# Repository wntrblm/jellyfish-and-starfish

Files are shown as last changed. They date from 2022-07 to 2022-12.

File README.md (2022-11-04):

# Jellyfish & Starfish

Jellyfish and Starfish are control boards designed for use with the LumenPnP. Starfish controls the base of the machine including X & Y axes and pneumatics. Jellyfish controls the head of the machine including the Z, A, and B axes.

## No support

Jellyfish and Starfish were made for Winterbloom's internal use cases and we don't have the resources to provide support. While we hope that this repository contains useful information for you, please note that issues and pull requests may go unanswered or may be closed without reply.

## License

Jellyfish and Starfish are open source, however, licensing a project like this is a little complicated. Please take a chance to review the [LICENSE](LICENSE.md) file.

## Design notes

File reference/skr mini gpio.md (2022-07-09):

IO00:   TXD0                UART0 TX
IO01:   RXD0                UART0 RX
IO02:   Z-EN                GPIO
IO03:   X-STOP              GPIO
IO04:   Y-STOP              GPIO
IO05:   Y-DIR               GPIO
IO06:   Y-STEP              GPIO
IO07:   Y-EN                GPIO
IO08:   TX4                 UART1 TX    (TMC UART)
IO09:   RX4                 UART1 RX    (TMC UART)
IO10:   X-DIR               GPIO
IO11:   X-STEP              GPIO
IO12:   X-EN                GPIO
IO13:   E0-DIR              GPIO
IO14:   E0-STEP             GPIO
IO15:   E0-EN               GPIO
IO16:   E0-STOP             GPIO
IO17:   FAN1_PWM            PWM0 B
IO18:   FAN2_PWM            PWM1 A
IO19:   Z-STEP              GPIO
IO20:   FAN3_PWM            PWM2 A
IO21:   HB_PWM              PWM2 B
IO22:   P2                  ?
IO23:   HE PWM              PWM3 B
IO24:   RGB                 GPIO
IO25:   Z-STOP              GPIO
IO26:   THB                 ?
IO27:   TH0                 ?
IO28:   Z-DIR               GPIO
IO29:   SERVOS_ADC3         PWM6 B

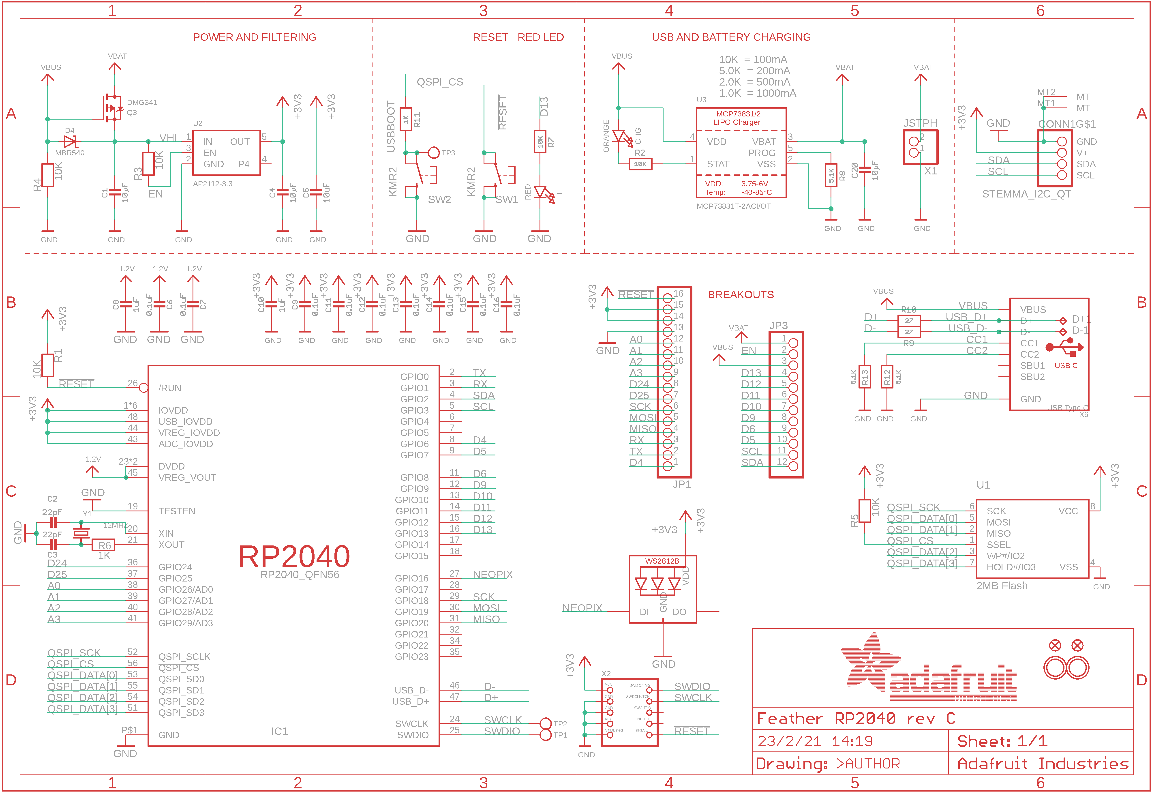
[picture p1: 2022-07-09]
reference/adafruit_products_FeatherRP_sch.png

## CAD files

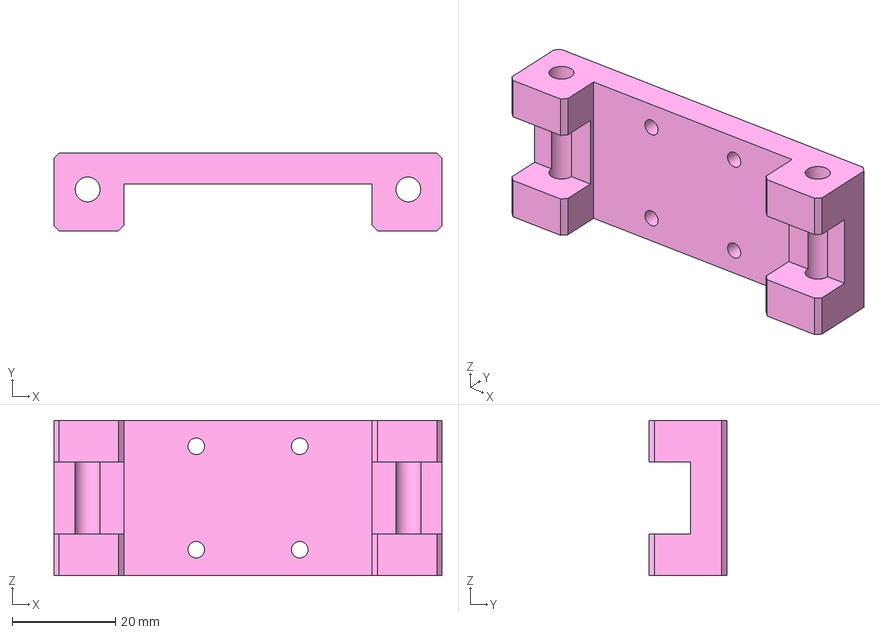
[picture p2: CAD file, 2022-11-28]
mechanical/x-gantry-block-mount-heat-set.FCStd
75.0 x 15.0 x 30.0 mm

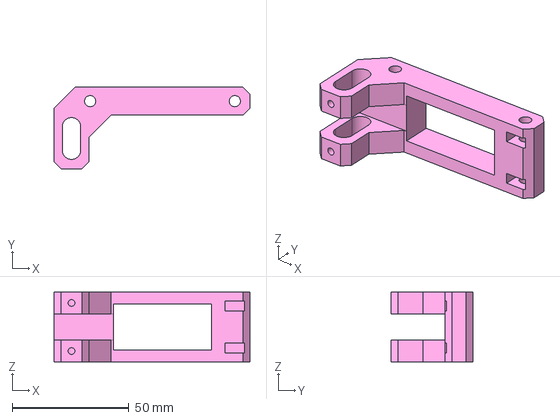
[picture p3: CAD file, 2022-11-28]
mechanical/x-gantry-block-mount-with-prox.FCStd
84.0 x 35.0 x 30.0 mm

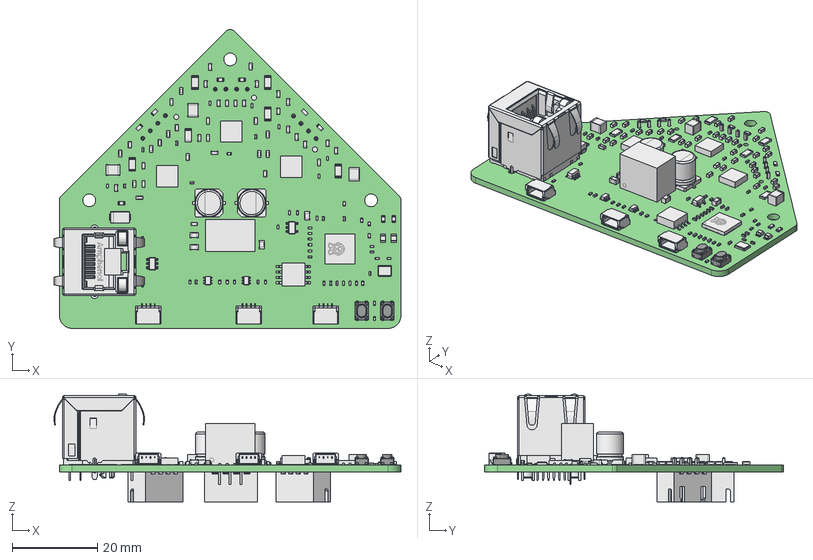
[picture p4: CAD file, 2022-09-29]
mechanical/jellyfish-pcb.FCStd
81.3 x 70.0 x 25.3 mm
jellyfish PCB

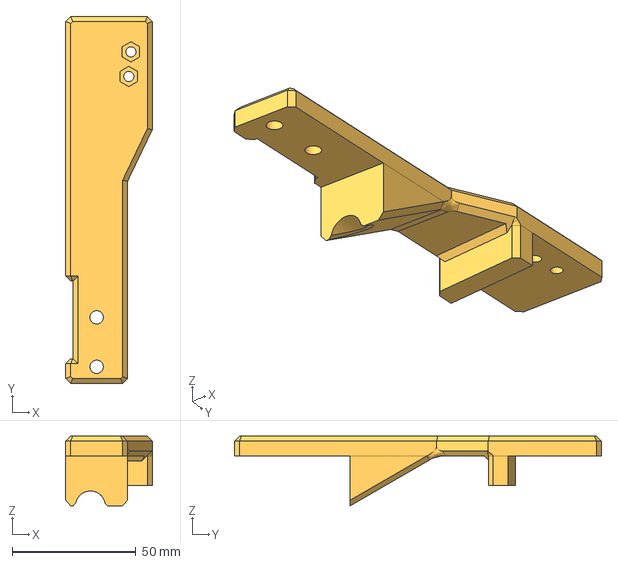
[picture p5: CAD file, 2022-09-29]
mechanical/front-drag-chain-mount.FCStd
35.0 x 148.4 x 28.2 mm

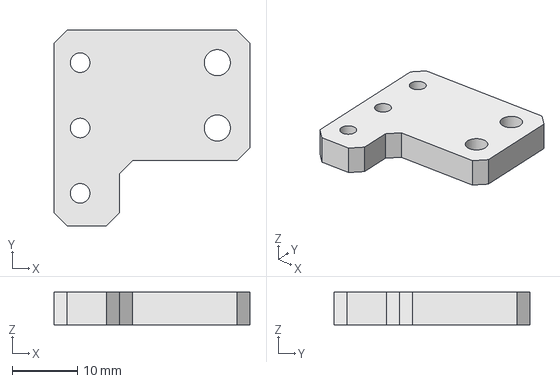
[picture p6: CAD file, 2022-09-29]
mechanical/drag chain mount.FCStd
30.0 x 30.0 x 5.00 mm

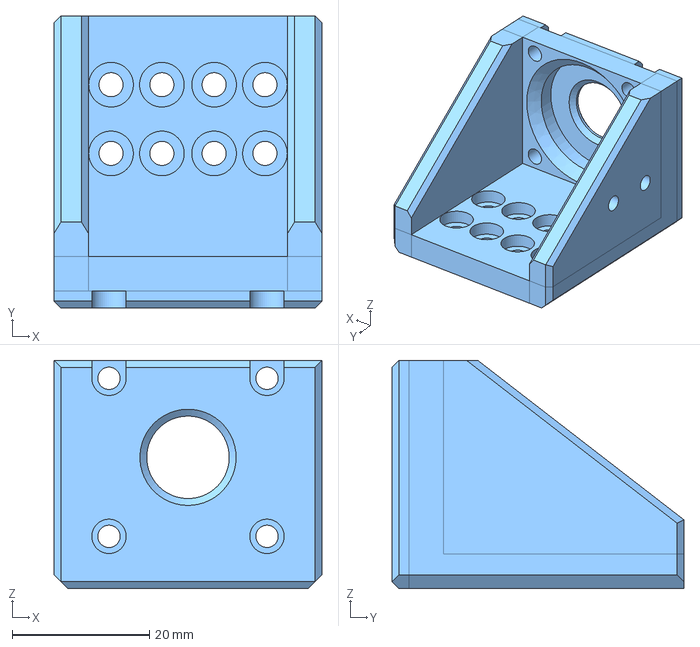
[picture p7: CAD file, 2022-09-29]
mechanical/z-gantry.FCStd
39.0 x 42.5 x 33.2 mm

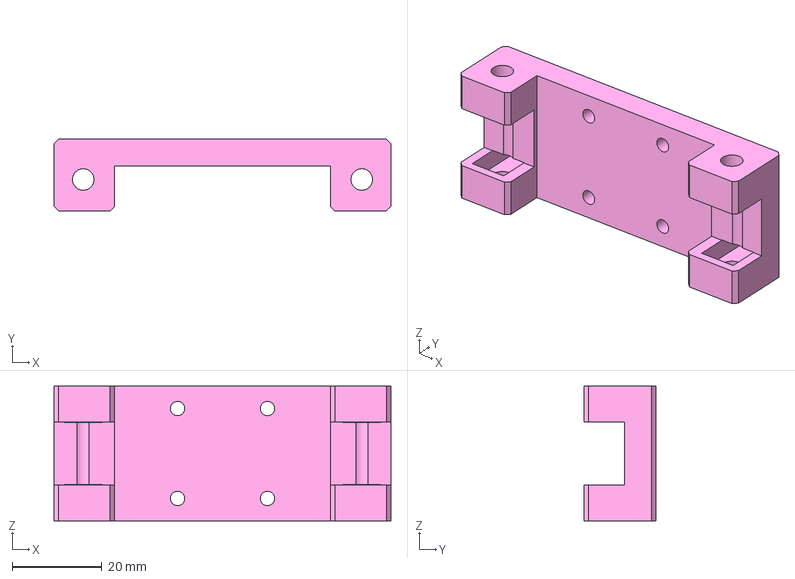
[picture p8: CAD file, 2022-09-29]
mechanical/x-gantry-block-mount.FCStd
75.0 x 16.0 x 30.0 mm

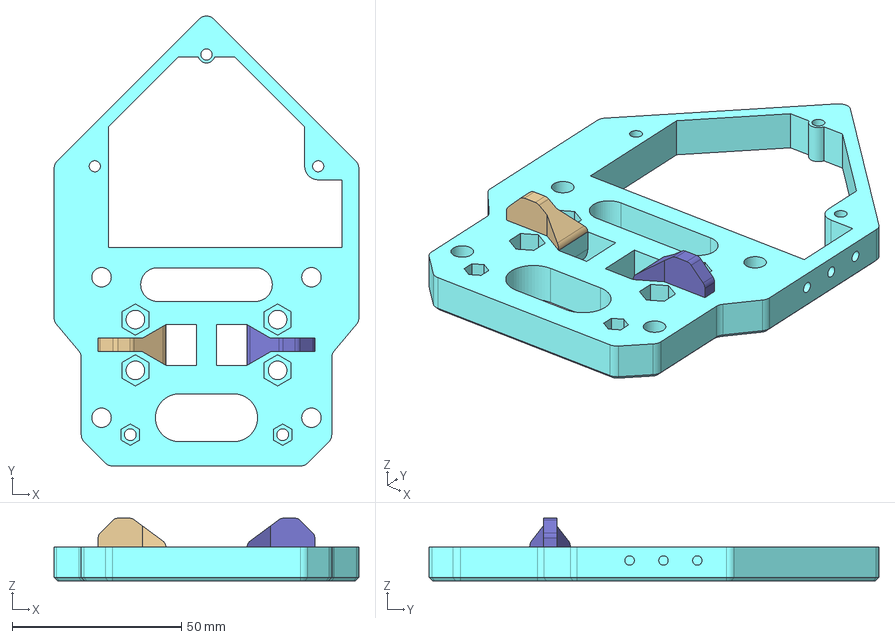
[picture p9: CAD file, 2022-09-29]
mechanical/x-gantry-back.FCStd
90.0 x 132.9 x 18.5 mm
BeltStandoff
BeltStandoff (Mirror #1)

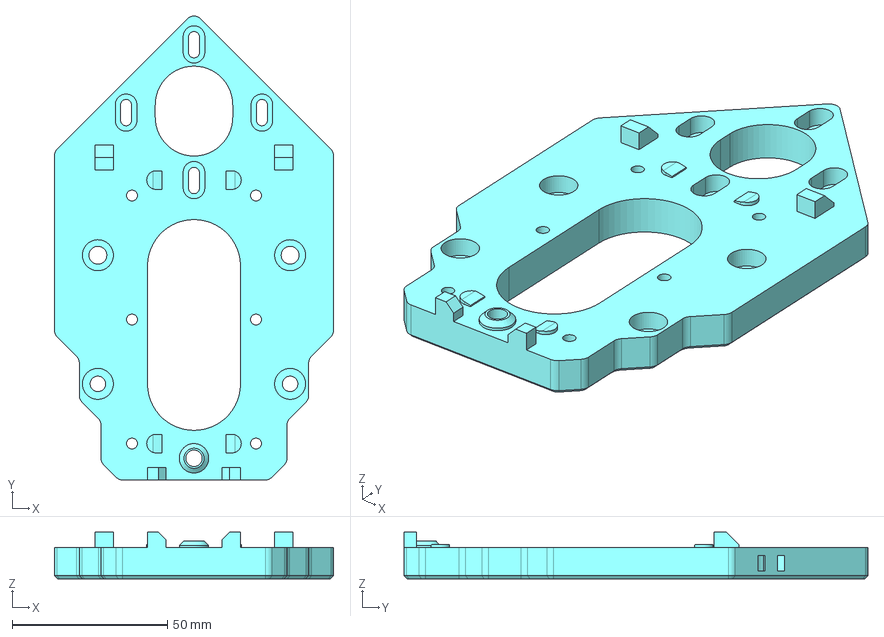
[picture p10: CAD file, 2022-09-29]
mechanical/x-gantry-front.FCStd
90.0 x 149.7 x 15.0 mm

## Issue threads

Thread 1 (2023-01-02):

Some BOM issues i found while sourcing parts

casartar, 2023-01-02:
Starfish BOM issues:
- C203, C1411, C1511, C1611 Capacitor 865080653016 seems to be too big for the footprint | suggestion: same as C5, C22 on Jellyfish EEE-TQV101XAP
- D401 - D404 different mpn, some for 5V instead of 3V3 | suggestion: should all be the same PESD3V3U1UA,115
- F201 fuse should be part of the schematic so it is included in the BOM | no suggestion: forgot to buy one :(
- J407 mpn is missing | suggestion: USB1030-GF-P-B-B
- R202, R1003, R1103, R1303, R1703 footprint is 0402 mpn is for 0603 | suggestion: AC0402FR-075K1L
- R403, R404 mpn missing | suggestion: same as R203
- SW301, SW302 mpn missing | suggestion: TS20-42-25-WT-160-SMT-TR
- U601, U701 pressure range missing

Jellyfish BOM issues:
- C1-C3 mpn missing | suggestion: C2012X7R1V475K125AE
- FB1-FB14 Value says 50 Ohm at 100 MHz but the Datasheet of the mpn says 120 Ohm and there are different ratings some 2A some 3A
- R3, R16 value is 100 mpn is for 10k | suggestion: AC0402JR-07100RL
- R18, R19, R21, R22, R24, R25 value is 220m but mpn is for 240m and it is different to starfish - i tried to understand this from the datasheed but didn't :|
- R1, R2, R15, R26, R27 value is 5k1 mpn is for 10k | suggestion: same as in starfish AC0402FR-075K1L
- R10, R28 mpn is missing | suggestion: RC0603JR-7W1KL

Jellyfish-Tailboard BOM issues:
- C1-C3 mpn missing | suggestion: EMZR500ARA101MF80G
- R1, R2, R3 value typo and footprint is 0402 but mpn is for 0603 | suggestion: AC0402FR-075K1L

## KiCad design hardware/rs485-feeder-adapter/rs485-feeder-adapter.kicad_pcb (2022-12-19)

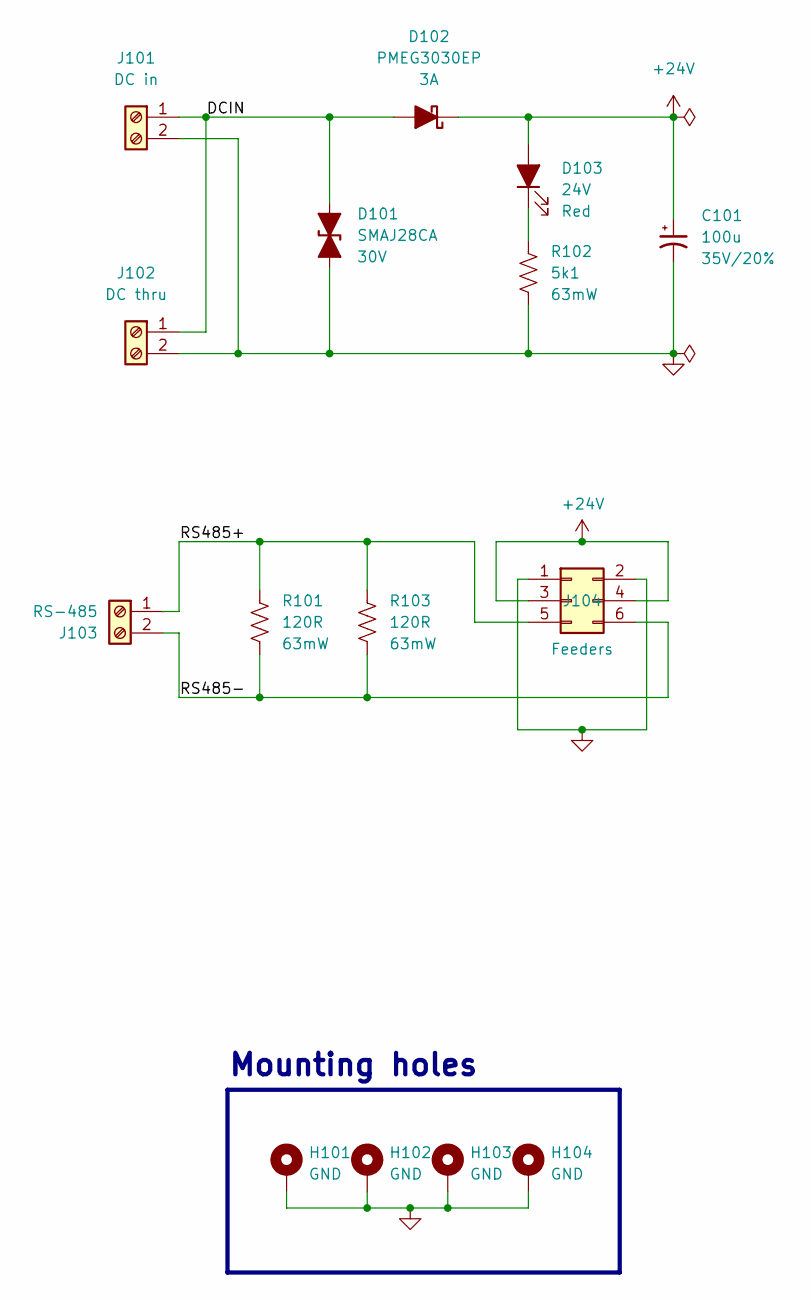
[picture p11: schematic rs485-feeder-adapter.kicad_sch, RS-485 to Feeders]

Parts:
C101: 100u; CP_Elec_6.3x9.9; Rating 35V/20%; mpn 865080653016, UWT1V221MNL1GS
D101: SMAJ28CA; D_SMA; Rating 30V; mpn SMAJ28CA
D102: PMEG3030EP; D_SOD-128; Rating 3A; mpn PMEG3030EP,115
D103: 24V; LED_0805_Kingbright_APT2012; Rating Red; mpn APT2012EC
H101, H102, H103, H104: GND; MountingHole_3mm_Pad
J101: DC in; TerminalBlock_CUI_TB002-500_1x02_P5.00mm_Vertical; mpn TB002-500-02BE
J102: DC thru; TerminalBlock_CUI_TB002-500_1x02_P5.00mm_Vertical; mpn TB002-500-02BE
J103: RS-485; TerminalBlock_4UCON_1x02_P3.50mm_Horizontal
J104: Feeders; IDC-Header_2x03_P2.54mm_Vertical
R101, R103: 120R; R_0402_HandSolder; Rating 63mW; mpn CRGCQ0402F120R
R102: 5k1; R_0402_HandSolder; Rating 63mW; mpn AC0603FR-075K1L

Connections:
+24V: C101.1, D102.1 (K), D103.2 (A), J104.3, J104.4
/DCIN: D101.1 (A1), D102.2 (A), J101.1, J102.1
/RS485+: J103.1, J104.5, R101.1, R103.1
/RS485-: J103.2, J104.6, R101.2, R103.2
GND: C101.2, D101.2 (A2), H101.1, H102.1, H103.1, H104.1, J101.2, J102.2, J104.1, J104.2, R102.2
unnamed: D103.1 (K), R102.1

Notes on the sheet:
Mounting holes

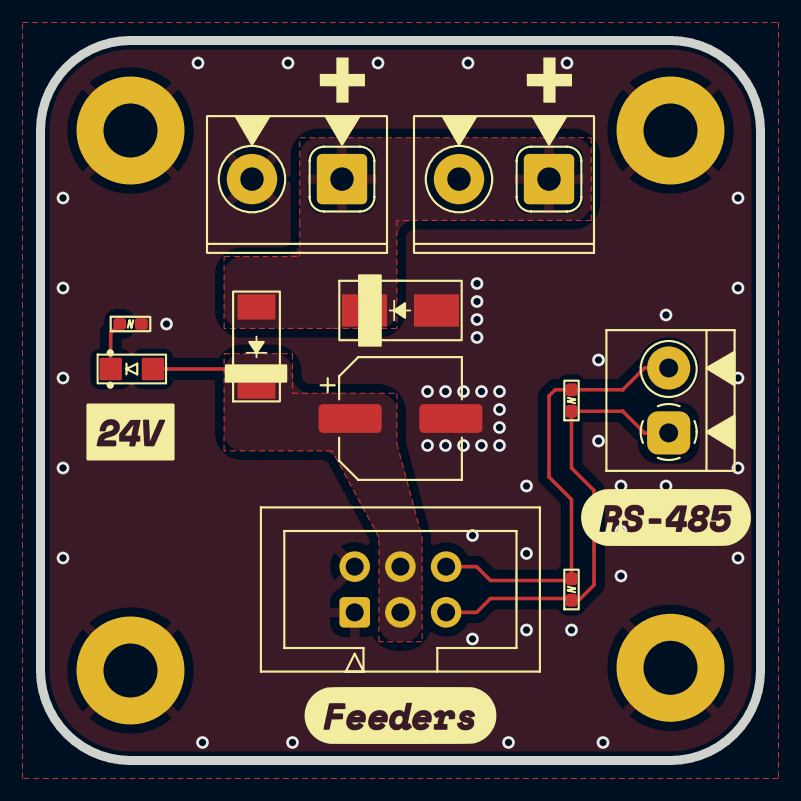
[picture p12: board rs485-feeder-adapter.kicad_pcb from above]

Board: 2 copper layers, 40.0 x 40.0 mm, 15 parts (0 on the bottom side), 6 nets.

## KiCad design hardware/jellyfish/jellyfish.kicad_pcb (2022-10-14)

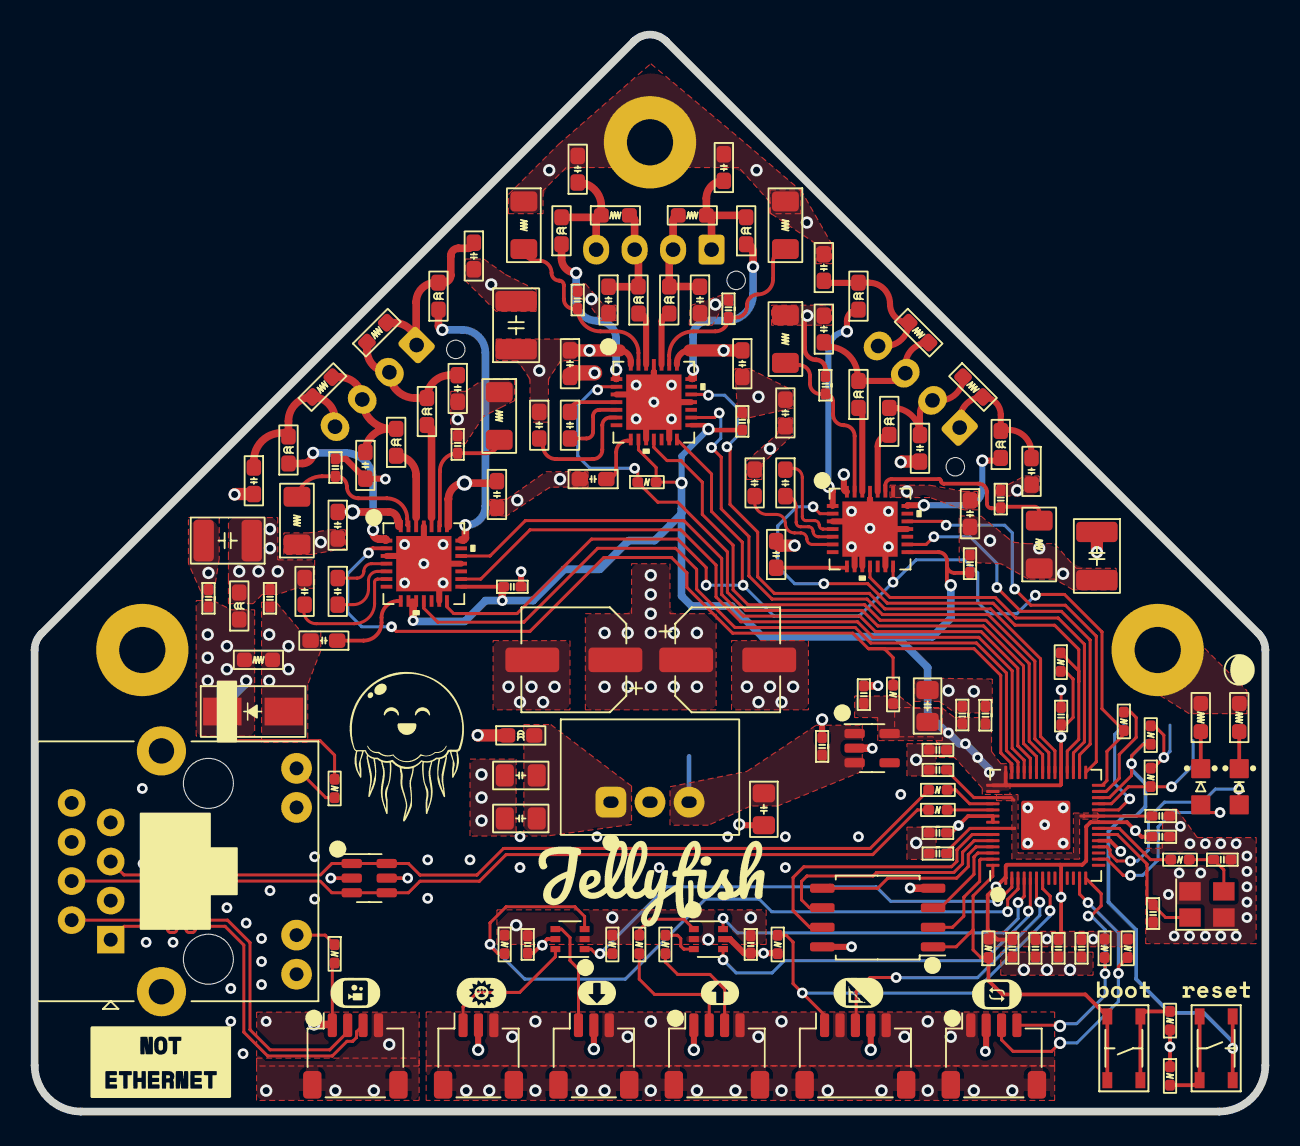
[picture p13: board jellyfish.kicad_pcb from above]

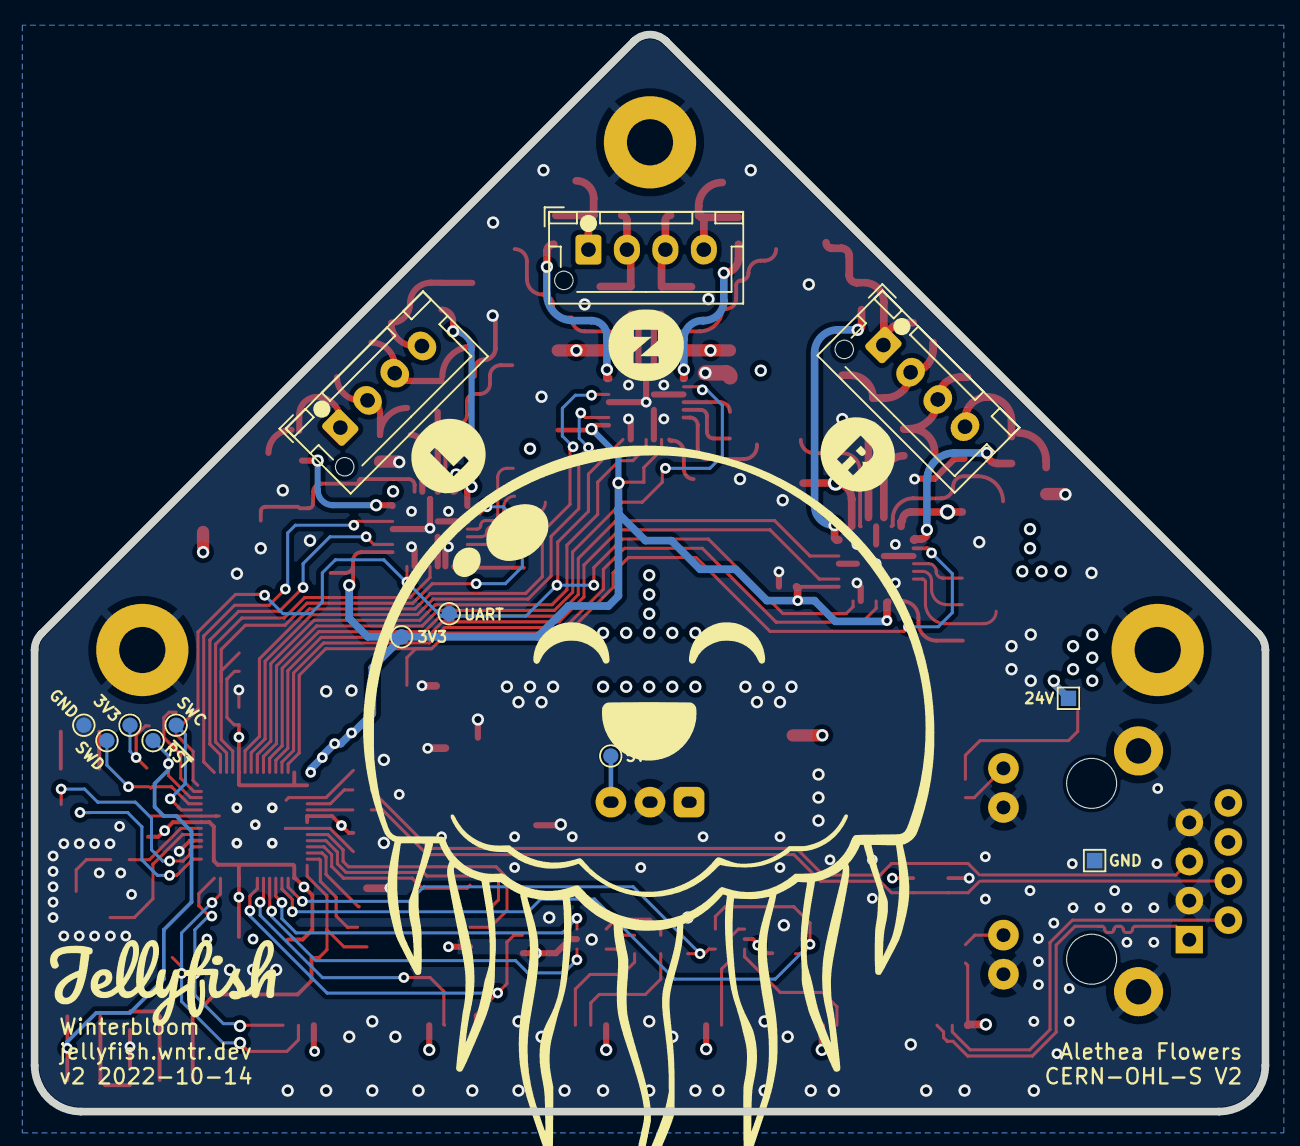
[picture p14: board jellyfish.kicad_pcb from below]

Board: 4 copper layers, 80.0 x 70.0 mm, 155 parts (13 on the bottom side), 103 nets.

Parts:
C1, C8, C9, C11, C12, C13, C14, C15, C16, C17, C20, C21, C25, C27, C29, C32, C33, C43, C46, C47, C57, C60, C61: 100n; C_0402_HandSolder
C2: 4.7u; C_0805_HandSolder
C3, C4: 22u; C_0805_HandSolder
C5, C22: 100u; CP_Elec_6.3x7.7
C6, C7, C18, C19, C26: 1u; C_0402_HandSolder
C10: 10u; C_0805_HandSolder
C23, C24: 15p; C_0402_HandSolder
C28, C42, C56: 22n; C_0603_HandSolder
C30, C36, C37, C44, C50, C51, C58, C64, C65: 100n; C_0603_HandSolder
C31, C45, C59: 4.7u; C_0603_HandSolder
C35, C49, C63: 10u; C_1210_HandSolder
C38, C39, C40, C41, C52, C53, C54, C55, C66, C67, C68, C69: 470p; C_0603_HandSolder
D1: AUX; LED_0805_Kingbright_APT2012
D2: SMAJ28A; D_SMA
D4: ACT; LED_0805_Kingbright_APT2012
FB1, FB2, FB3, FB4, FB5, FB6, FB7, FB8, FB9, FB10, FB11, FB12, FB13, FB14: 50Ω @ 100MHz; L_0603_HandSolder
H1, H2, H3: GND; MountingHole_3mm_Pad
J1: INS; JST_SH_SM04B-SRSS-TB_1x04-1MP_P1.00mm_Horizontal
J2: 8P8C_LED_Shielded; RJ45_Amphenol_RJE45-188-1411_Vertical
J3: CAM; JST_SH_SM04B-SRSS-TB_1x04-1MP_P1.00mm_Horizontal
J4: CAMLED; JST_SH_SM03B-SRSS-TB_1x03-1MP_P1.00mm_Horizontal
J5: OUT1; JST_SH_SM03B-SRSS-TB_1x03-1MP_P1.00mm_Horizontal
J6: BLTOUCH; JST_SH_SM05B-SRSS-TB_1x05-1MP_P1.00mm_Horizontal
J7, J8, J9: MOTOR; JST_XH_B4B-XH-AM_1x04_P2.50mm_Vertical
J10: Stemma QT; JST_SH_SM04B-SRSS-TB_1x04-1MP_P1.00mm_Horizontal
R1, R2, R15, R26, R27: 5.1k; R_0402_HandSolder
R3, R16: 100; R_0402_HandSolder
R4, R5, R12, R13, R14, R17, R20, R23: 10k; R_0402_HandSolder
R6, R7: 27R; R_0402_HandSolder
R8, R9, R11, R29: 1k; R_0402_HandSolder
R10, R28: 1k; R_0603_HandSolder
R18, R19, R21, R22, R24, R25: 220m; R_1206_HandSolder
RV1, RV2, RV3, RV4, RV5, RV6, RV7: 35V; R_0603_HandSolder
SW1: BOOTSEL; Tactile_Switch_4.2mm
SW2: RESET; Tactile_Switch_4.2mm
TP1: GND; TestPoint_Pad_1.0x1.0mm
TP2: 24V; TestPoint_Pad_1.0x1.0mm
TP3: 5V; TestPoint_Pad_D1.0mm
TP4, TP6: 3V3; TestPoint_Pad_D1.0mm
TP5: GND; TestPoint_Pad_D1.0mm
TP7: ~{RST}; TestPoint_Pad_D1.0mm
TP8: SWD; TestPoint_Pad_D1.0mm
TP9: SWC; TestPoint_Pad_D1.0mm
TP17: UART; TestPoint_Pad_D1.0mm
U1: VX7805-500; Converter_DCDC_CUI_VX78-500_THT
U2: MIC5317-3.3; SOT-23-5
U3: RP2040; RP2040-QFN-56
U4: W25Q128JVS; SOIC-8_5.23x5.23mm_P1.27mm
U5, U7: 74HC2G34; SOT-363_SC-70-6
U6: TVS; SOT-23-6
U8, U9, U10: TMC2209; TMC2209-LA
Y1: 12MHz; Crystal_SMD_Abracon_ABM8G-4Pin_3.2x2.5mm

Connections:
+1V1: C19.1, C20.1, C21.1, U3.23 (DVDD), U3.45 (VREG_VOUT), U3.50 (DVDD)
+3V3: C1.1, C7.1, C10.1, C11.1, C12.1, C13.1, C14.1, C15.1, C16.1, C17.1, C18.1, C25.1, C26.1, C29.1, C43.1, C57.1, J10.2, R4.2, R5.1, R12.2, R15.2, R17.2, R20.2, R23.2, R26.2, R27.2, TP4.1, TP6.1, U2.5 (OUT), U3.1 (IOVDD), U3.10 (IOVDD), U3.22 (IOVDD), U3.33 (IOVDD), U3.42 (IOVDD), U3.43 (ADC_AVDD), U3.44 (VREG_IN), U3.48 (USB_VDD), U3.49 (IOVDD), U4.8 (VCC), U5.5 (VCC), U8.15 (VCC_IO), U9.9 (MS1_AD0), U9.15 (VCC_IO), U10.9 (MS1_AD0), U10.10 (MS2_AD1), U10.15 (VCC_IO)
+5V: C4.1, C6.1, C27.1, J1.1, J3.1, J4.2, J5.2, J6.4, R1.2, TP3.1, U1.3 (Vout), U2.1 (IN), U2.3 (EN), U6.5 (VBUS), U7.5 (VCC)
+24V: C5.1, C9.1, C22.1, C30.1, C35.1, C36.1, C37.1, C44.1, C49.1, C50.1, C51.1, C58.1, C63.1, C64.1, C65.1, FB1.2, U8.22 (VS), U8.28 (VS), U9.22 (VS), U9.28 (VS), U10.22 (VS), U10.28 (VS)
/Connections/AUX_OUT: R14.2, U3.3 (GPIO1), U7.3 (2A)
/Connections/BLTOUCH_CONTROL: J6.3, U3.6 (GPIO4)
/Connections/BLTOUCH_OUT: J6.1, R15.1, U3.7 (GPIO5)
/Connections/CAM_D+: J2.1, J3.3
/Connections/CAM_D-: J2.2, J3.2
/Connections/CAM_LED: R13.2, U3.2 (GPIO0), U7.1 (1A)
/Connections/IN_1: U3.4 (GPIO2), U5.6 (1Y)
/Connections/IN_2: U3.5 (GPIO3), U5.4 (2Y)
/Connections/MCU_D+: J2.4, R6.1, U6.3 (D+), U6.4 (D+)
/Connections/MCU_D-: J2.5, R7.1, U6.1 (D-), U6.6 (D-)
/Connections/QWIIC_SCL: J10.4, R27.1, U3.14 (GPIO11)
/Connections/QWIIC_SDA: J10.3, R26.1, U3.13 (GPIO10)
/Left Motor/5VOUT: C31.1, U8.8 (5VOUT)
/Left Motor/BRA: C33.1, R19.2, U8.23 (BRA)
/Left Motor/BRB: C32.1, R18.2, U8.27 (BRB)
/Left Motor/CPI: C28.2, U8.5 (CPI)
/Left Motor/CPO: C28.1, U8.4 (CPO)
/Left Motor/DIAG: U3.31 (GPIO20), U8.11 (DIAG)
/Left Motor/DIR: U3.29 (GPIO18), U8.19 (DIR)
/Left Motor/ENN: R17.1, U3.32 (GPIO21), U8.2 (ENN)
/Left Motor/OA1: FB4.1, U8.24 (OA1)
/Left Motor/OA2: FB5.1, U8.21 (OA2)
/Left Motor/OB1: FB3.1, U8.26 (OB1)
/Left Motor/OB2: FB2.1, U8.1 (OB2)
/Left Motor/STEP: U3.30 (GPIO19), U8.16 (STEP)
/Left Motor/VCP: C30.2, U8.6 (VCP)
/Microcontroller/ACT_LED: D4.2 (A), U3.18 (GPIO15)
/Microcontroller/AUX_LED: D1.2 (A), U3.16 (GPIO13)
/Microcontroller/M1_DIAG: U3.36 (GPIO24), U9.11 (DIAG)
/Microcontroller/M1_DIR: U3.34 (GPIO22), U9.19 (DIR)
/Microcontroller/M1_EN: R20.1, U3.37 (GPIO25), U9.2 (ENN)
/Microcontroller/M1_STEP: U3.35 (GPIO23), U9.16 (STEP)
/Microcontroller/M2_DIAG: U3.40 (GPIO28_ADC2), U10.11 (DIAG)
/Microcontroller/M2_DIR: U3.38 (GPIO26_ADC0), U10.19 (DIR)
/Microcontroller/M2_EN: R23.1, U3.41 (GPIO29_ADC3), U10.2 (ENN)
/Microcontroller/M2_STEP: U3.39 (GPIO27_ADC1), U10.16 (STEP)
/Microcontroller/QSPI_CS: R12.1, SW1.1, U3.56 (QSPI_SS), U4.1 (~CS)
/Microcontroller/QSPI_SCLK: U3.52 (QSPI_SCLK), U4.6 (CLK)
/Microcontroller/QSPI_SD0: U3.53 (QSPI_SD0), U4.5 (DI(IO0))
/Microcontroller/QSPI_SD1: U3.55 (QSPI_SD1), U4.2 (DO(IO1))
/Microcontroller/QSPI_SD2: U3.54 (QSPI_SD2), U4.3 (IO2)
/Microcontroller/QSPI_SD3: U3.51 (QSPI_SD3), U4.7 (IO3)
/Microcontroller/RUN: R4.1, SW2.1, TP7.1, U3.26 (RUN)
/Microcontroller/SWCLK: TP9.1, U3.24 (SWCLK)
/Microcontroller/SWD: R5.2, TP8.1, U3.25 (SWD)
/Microcontroller/UART1_TX: R8.1, U3.27 (GPIO16)
/Microcontroller/USB_D+: R6.2, U3.47 (USB_DP)
/Microcontroller/USB_D-: R7.2, U3.46 (USB_DM)
/Microcontroller/XIN: C23.1, U3.20 (XIN), Y1.1
/Microcontroller/XOUT: R11.1, U3.21 (XOUT)
/Power/VIN_FILTERED: C2.1, C3.1, FB14.2, U1.1 (Vin)
/Right Motor/5VOUT: C59.1, U10.8 (5VOUT)
/Right Motor/BRA: C61.1, R25.2, U10.23 (BRA)
/Right Motor/BRB: C60.1, R24.2, U10.27 (BRB)
/Right Motor/CPI: C56.2, U10.5 (CPI)
/Right Motor/CPO: C56.1, U10.4 (CPO)
/Right Motor/OA1: FB12.1, U10.24 (OA1)
/Right Motor/OA2: FB13.1, U10.21 (OA2)
/Right Motor/OB1: FB11.1, U10.26 (OB1)
/Right Motor/OB2: FB10.1, U10.1 (OB2)
/Right Motor/VCP: C58.2, U10.6 (VCP)
/TMC_UART: R8.2, TP17.1, U3.28 (GPIO17), U8.14 (PDN_UART), U9.14 (PDN_UART), U10.14 (PDN_UART)
/Z Motor/5VOUT: C45.1, U9.8 (5VOUT)
/Z Motor/BRA: C47.1, R22.2, U9.23 (BRA)
/Z Motor/BRB: C46.1, R21.2, U9.27 (BRB)
/Z Motor/CPI: C42.2, U9.5 (CPI)
/Z Motor/CPO: C42.1, U9.4 (CPO)
/Z Motor/OA1: FB8.1, U9.24 (OA1)
/Z Motor/OA2: FB9.1, U9.21 (OA2)
/Z Motor/OB1: FB7.1, U9.26 (OB1)
/Z Motor/OB2: FB6.1, U9.1 (OB2)
/Z Motor/VCP: C44.2, U9.6 (VCP)
GND: C1.2, C2.2, C3.2, C4.2, C5.2, C6.2, C7.2, C8.2, C9.2, C10.2, C11.2, C12.2, C13.2, C14.2, C15.2, C16.2, C17.2, C18.2, C19.2, C20.2, C21.2, C22.2, C23.2, C24.2, C25.2, C26.2, C27.2, C29.2, C31.2, C32.2, C33.2, C35.2, C36.2, C37.2, C38.2, C39.2, C40.2, C41.2, C43.2, C45.2, C46.2, C47.2, C49.2, C50.2, C51.2, C52.2, C53.2, C54.2, C55.2, C57.2, C59.2, C60.2, C61.2, C63.2, C64.2, C65.2, C66.2, C67.2, C68.2, C69.2, D2.2 (A), H1.1, H2.1, H3.1, J1.4, J1.MP (MountPin), J2.3, J2.7, J2.9, J2.11, J2.SH, J3.4, J3.MP (MountPin), J4.3, J4.MP (MountPin), J5.3, J5.MP (MountPin), J6.2, J6.5, J6.MP (MountPin), J10.1, J10.MP (MountPin), R9.1, R10.2, R13.1, R14.1, R18.1, R19.1, R21.1, R22.1, R24.1, R25.1, R28.2, R29.1, RV1.2, TP1.1, TP5.1, U1.2 (GND), U2.2 (GND), U3.19 (TESTEN), U3.57 (GND), U4.4 (GND), U5.2 (GND), U6.2 (GND), U7.2 (GND), U8.3 (GND), U8.9 (MS1_AD0), U8.10 (MS2_AD1), U8.13 (CLK), U8.18 (GND), U8.25 (GND), U8.29 (PAD), U9.3 (GND), U9.10 (MS2_AD1), U9.13 (CLK), U9.18 (GND), U9.25 (GND), U9.29 (PAD), U10.3 (GND), U10.13 (CLK), U10.18 (GND), U10.25 (GND), U10.29 (PAD), Y1.2, Y1.4
unnamed: C24.1, R11.2, Y1.3
unnamed: C38.1, FB3.2, J7.3, RV2.2
unnamed: C39.1, FB5.2, J7.1, RV3.2
unnamed: C40.1, FB2.2, J7.4, RV2.1
unnamed: C41.1, FB4.2, J7.2, RV3.1
unnamed: C52.1, FB7.2, J8.3, RV4.2
unnamed: C53.1, FB9.2, J8.1, RV5.2
unnamed: C54.1, FB6.2, J8.4, RV4.1
unnamed: C55.1, FB8.2, J8.2, RV5.1
unnamed: C66.1, FB11.2, J9.3, RV6.2
unnamed: C67.1, FB13.2, J9.1, RV7.2
unnamed: C68.1, FB10.2, J9.4, RV6.1
unnamed: C69.1, FB12.2, J9.2, RV7.1
unnamed: D1.1 (K), R28.1
unnamed: D4.1 (K), R10.1
unnamed: J1.2, R3.2
unnamed: J1.3, R16.2
unnamed: J2.10, R1.1
unnamed: J2.12, R2.1
unnamed: J4.1, U7.6 (1Y)
unnamed: J5.1, U7.4 (2Y)
unnamed: R3.1, U5.1 (1A)
unnamed: R9.2, SW1.2
unnamed: R16.1, U5.3 (2A)
unnamed: R29.2, SW2.2
VDC: C8.1, D2.1 (K), FB1.1, FB14.1, J2.6, J2.8, R2.2, RV1.1, TP2.1

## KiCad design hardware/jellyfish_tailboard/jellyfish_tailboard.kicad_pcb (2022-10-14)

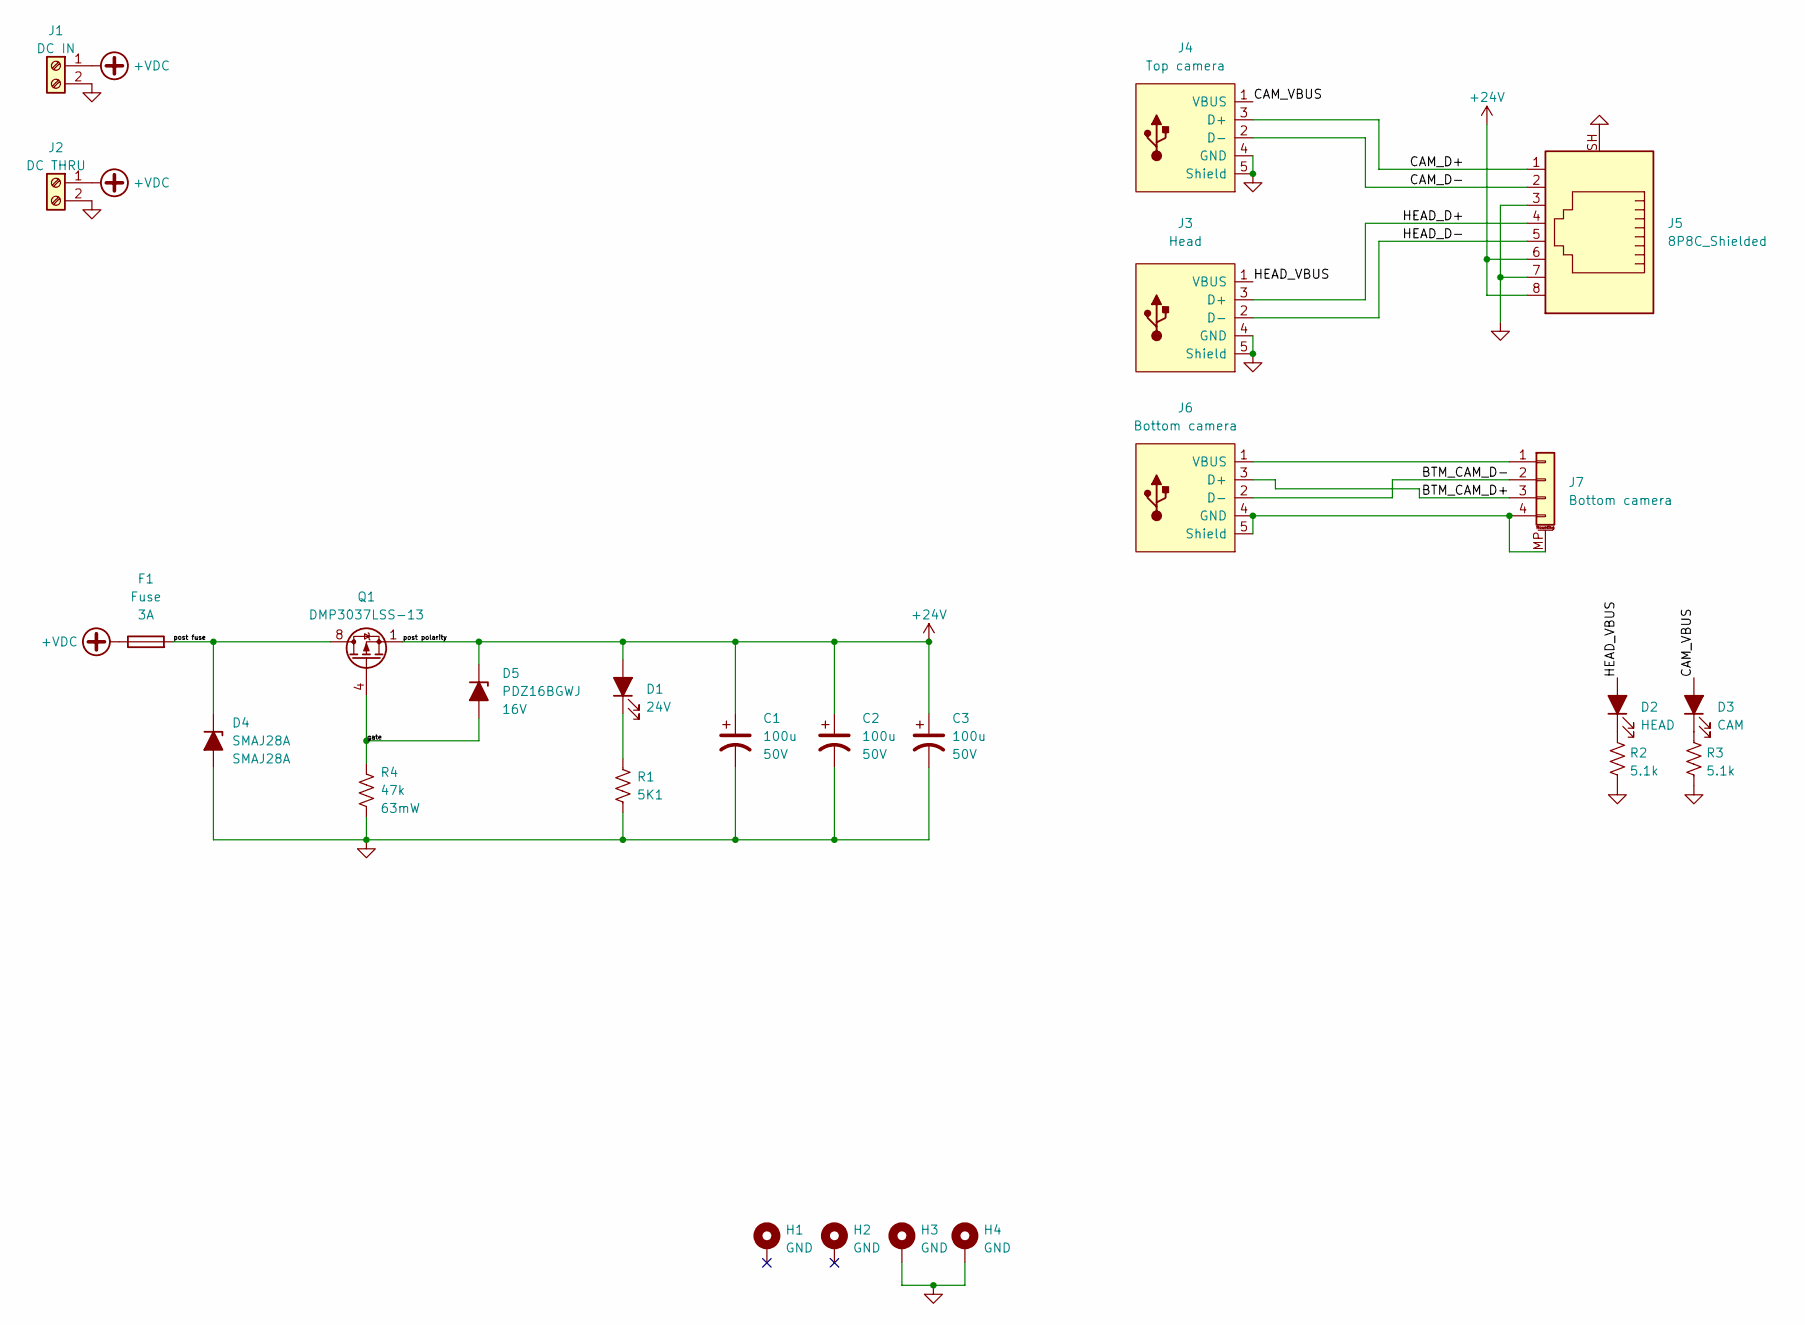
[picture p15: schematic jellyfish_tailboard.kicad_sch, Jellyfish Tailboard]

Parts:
C1, C2, C3: 100u; CP_Elec_6.3x9.9; Rating 50V
D1: 24V; LED_0805_Kingbright_APT2012; mpn APT2012EC
D2: HEAD; LED_0805_Kingbright_APT2012; mpn APT2012EC
D3: CAM; LED_0805_Kingbright_APT2012; mpn APT2012EC
D4: SMAJ28A; D_SMA; Rating 30V; mpn SMAJ28A
D5: PDZ16BGWJ; D_SOD-123; Rating 16V; mpn PDZ16BGWJ
F1: Fuse; Fuseholder_Blade_Mini_Keystone_3568; Rating 3A
H1, H2, H3, H4: GND; MountingHole_3mm_Pad
J1: DC IN; TerminalBlock_CUI_TB002-500_1x02_P5.00mm_Vertical; mpn TB002-500-02BE
J2: DC THRU; TerminalBlock_CUI_TB002-500_1x02_P5.00mm_Vertical; mpn TB002-500-02BE
J3: Head; USB_B_Receptacle_Horizontal; mpn 5787834-1
J4: Top camera; USB_B_Receptacle_Horizontal; mpn 5787834-1
J5: 8P8C_Shielded; Connector_RJ45_SS-7188S-A-PG4-BA-50
J6: Bottom camera; USB_B_Receptacle_Horizontal; mpn 5787834-1
J7: Bottom camera; JST_SH_SM04B-SRSS-TB_1x04-1MP_P1.00mm_Horizontal
Q1: DMP3037LSS-13; SOIC-8_3.9x4.9mm_P1.27mm
R1: 5K1; R_0402_HandSolder; mpn AC0603FR-075K1L
R2, R3: 5.1k; R_0402_HandSolder; mpn AC0603FR-075K1L
R4: 47k; R_0402_HandSolder; Rating 63mW; mpn RC0402FR-0747KL

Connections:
+24V: C1.1, C2.1, C3.1, D1.2 (A), D5.1 (K), J5.6, J5.8, Q1.1 (S), Q1.2 (S), Q1.3 (S)
+VDC: F1.1, J1.1, J2.1
/BTM_CAM_D+: J6.3 (D+), J7.3
/BTM_CAM_D-: J6.2 (D-), J7.2
/CAM_D+: J4.3 (D+), J5.1
/CAM_D-: J4.2 (D-), J5.2
/CAM_VBUS: D3.2 (A), J4.1 (VBUS)
/HEAD_D+: J3.3 (D+), J5.4
/HEAD_D-: J3.2 (D-), J5.5
/HEAD_VBUS: D2.2 (A), J3.1 (VBUS)
/gate: D5.2 (A), Q1.4 (G), R4.1
/post fuse: D4.1 (K), F1.2, Q1.5 (D), Q1.6 (D), Q1.7 (D), Q1.8 (D)
GND: C1.2, C2.2, C3.2, D4.2 (A), H3.1, H4.1, J1.2, J2.2, J3.4 (GND), J3.5 (Shield), J4.4 (GND), J4.5 (Shield), J5.3, J5.7, J5.SH, R1.2, R2.2, R3.2, R4.2
unnamed: D1.1 (K), R1.1
unnamed: D2.1 (K), R2.1
unnamed: D3.1 (K), R3.1
unnamed: J6.1 (VBUS), J7.1
unnamed: J6.4 (GND), J6.5 (Shield), J7.4, J7.MP (MountPin)

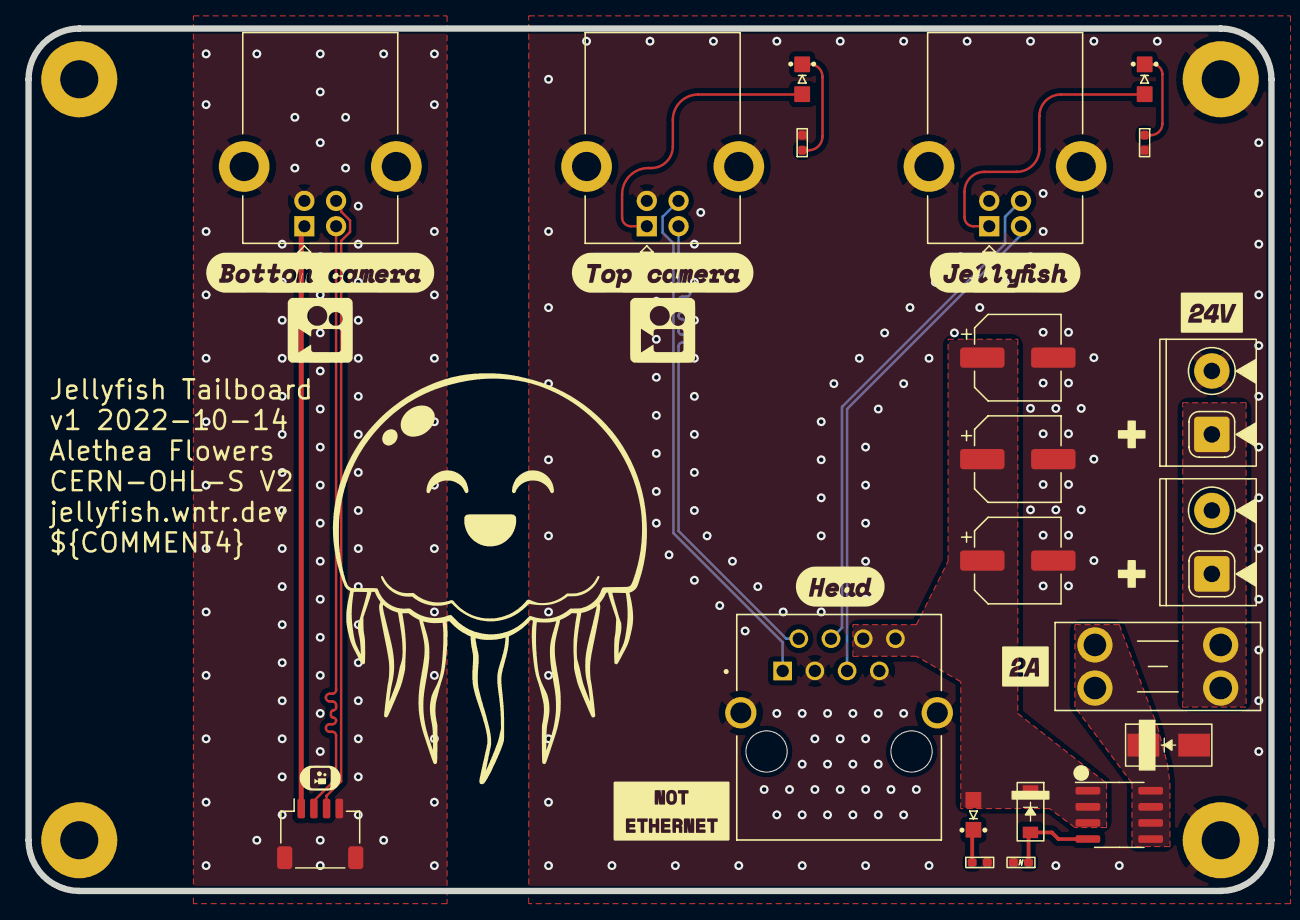
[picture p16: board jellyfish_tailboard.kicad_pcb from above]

Board: 2 copper layers, 98.0 x 68.0 mm, 25 parts (0 on the bottom side), 18 nets.

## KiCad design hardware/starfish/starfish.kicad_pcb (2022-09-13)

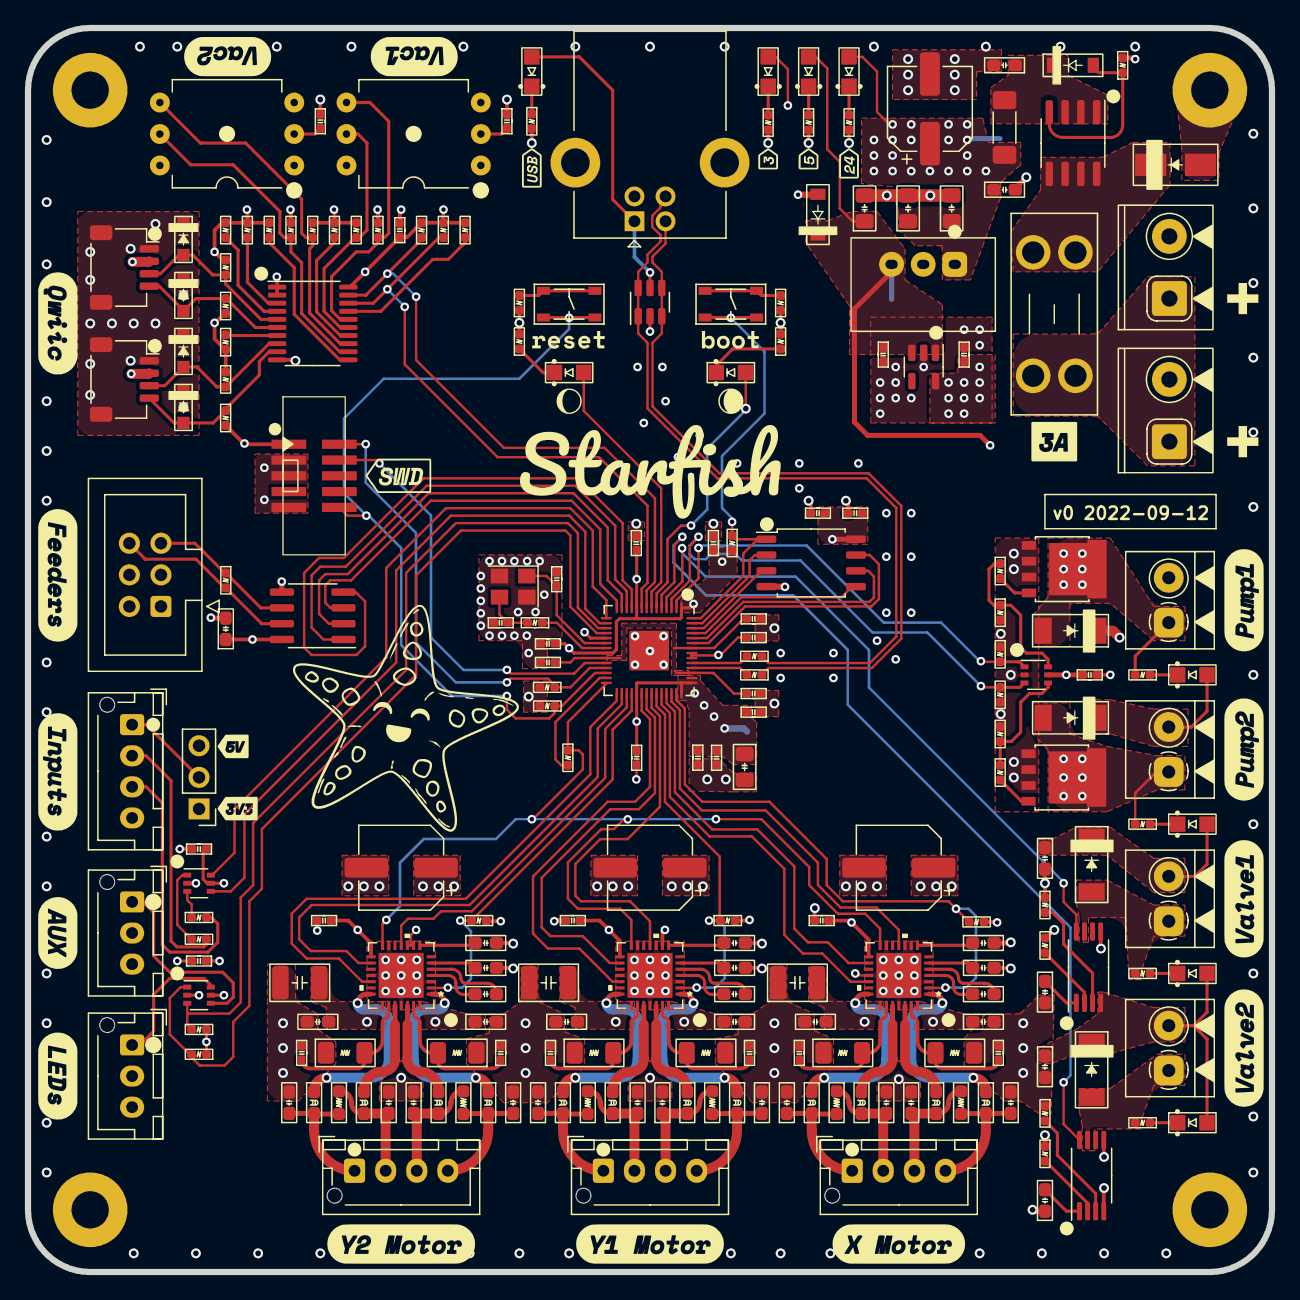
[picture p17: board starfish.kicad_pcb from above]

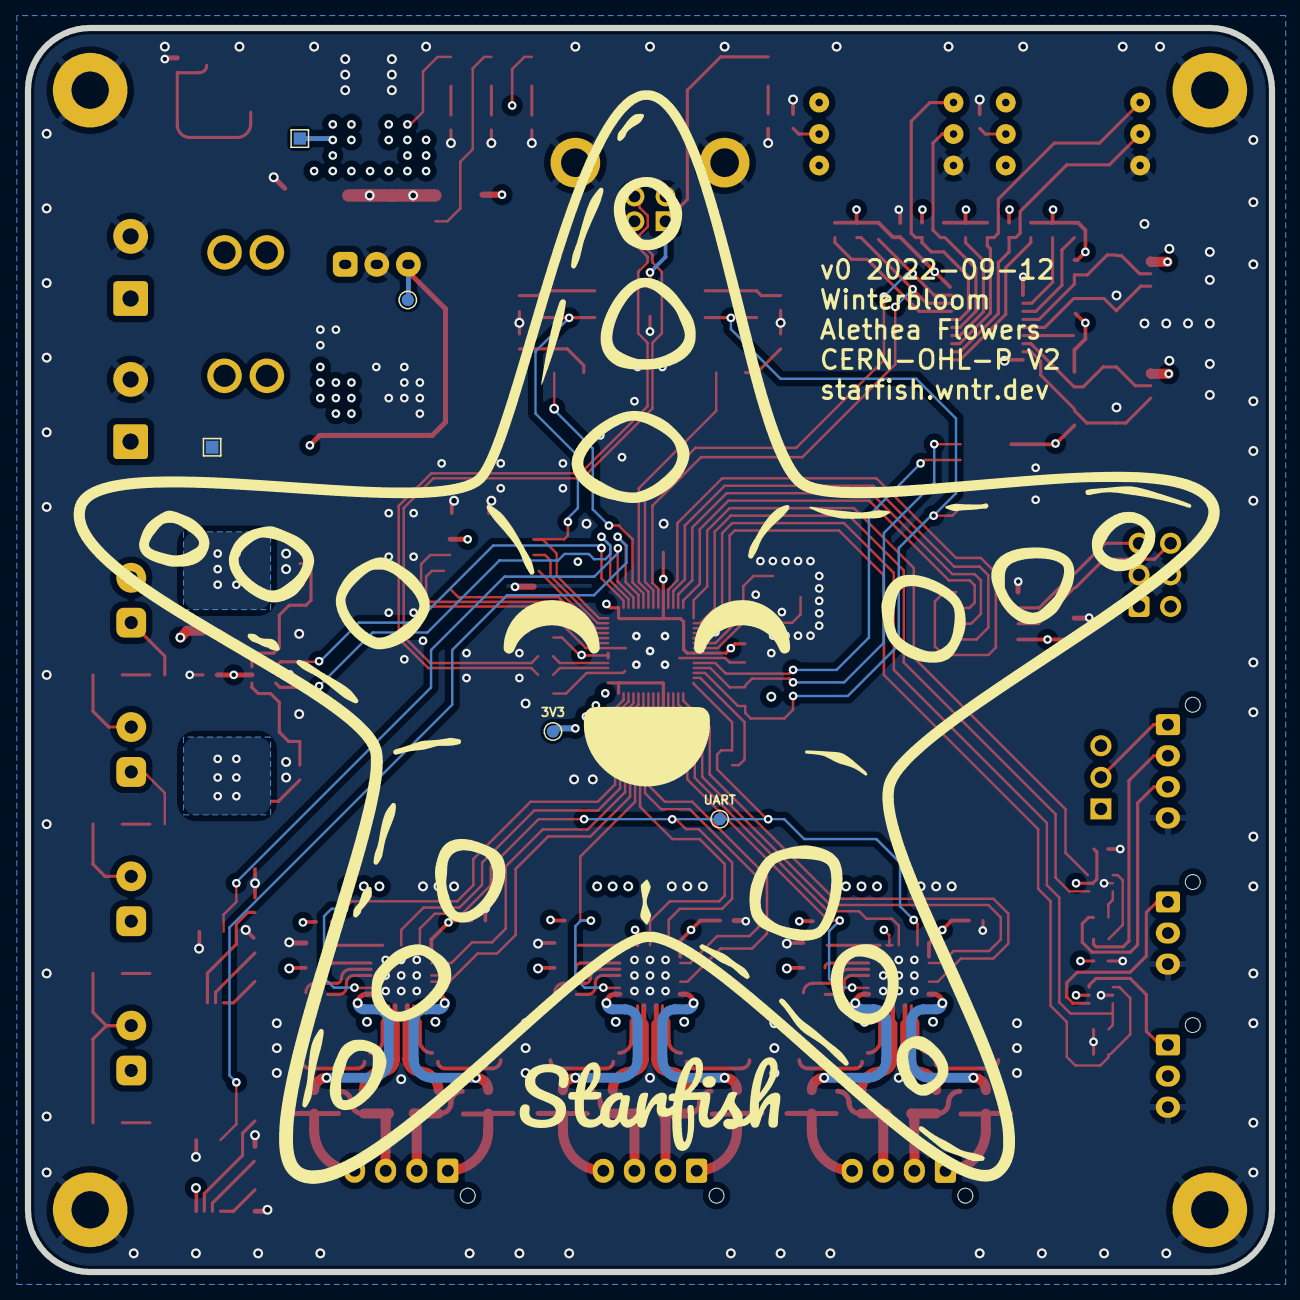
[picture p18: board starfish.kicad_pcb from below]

Board: 4 copper layers, 100.0 x 100.0 mm, 228 parts (5 on the bottom side), 147 nets.

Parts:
C201, C202, C801, C1202, C1302, C1403, C1413, C1414, C1503, C1513, C1514, C1603, C1613, C1614: 100n; C_0603_HandSolder
C203, C1411, C1511, C1611: 100u; CP_Elec_6.3x9.9
C206: 4u7; C_0805_HandSolder
C207, C208: 22u; C_0805_HandSolder
C209, C210, C309, C310, C316: 1u; C_0402_HandSolder
C301: 10u; C_0805_HandSolder
C302, C303, C304, C305, C306, C307, C308, C311, C312, C315, C401, C402, C501, C601, C701, C901, C1402, C1405, C1406, C1502, C1505, C1506, C1602, C1605, C1606: 100n; C_0402_HandSolder
C313, C314: 15p; C_0402_HandSolder
C1201, C1301, C1404, C1504, C1604: 4u7; C_0603_HandSolder
C1401, C1501, C1601: 22n; C_0603_HandSolder
C1407, C1408, C1409, C1410, C1507, C1508, C1509, C1510, C1607, C1608, C1609, C1610: 470p; C_0603_HandSolder
C1412, C1512, C1612: 10u; C_1210_HandSolder
D201: SMAJ28A; D_SMA
D202: PDZ16BGWJ; D_SOD-123
D203: 24V; LED_0805_Kingbright_APT2012
D204: 5V; LED_0805_Kingbright_APT2012
D205: 3V3; LED_0805_Kingbright_APT2012
D301: Act; LED_0805_Kingbright_APT2012
D302: Aux; LED_0805_Kingbright_APT2012
D401, D402, D403, D404: PESD5V; D_SOD-323
D405: PMEG2005EGWJ; D_SOD-123
D406: USB; LED_0805_Kingbright_APT2012
D1001, D1101, D1201, D1301: On; LED_0805_Kingbright_APT2012
D1002, D1102, D1202, D1302: PMEG3030EP; D_SOD-128
F201: Fuse; Fuseholder_Blade_Mini_Keystone_3568
FB201: 60R @ 100MHz; L_1806_4516Metric_Pad1.45x1.90mm_HandSolder
FB1401, FB1402, FB1403, FB1404, FB1501, FB1502, FB1503, FB1504, FB1601, FB1602, FB1603, FB1604: 120R @ 100MHz; L_0603_HandSolder
H101, H102, H103, H104: GND; MountingHole_3mm_Pad
J1: SWD; Connector_Cortex_Debug_IDC_2x05_P1.27mm_Vertical_Shrouded_S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
J201: DC in; TerminalBlock_CUI_TB002-500_1x02_P5.00mm_Vertical
J202: DC thru; TerminalBlock_CUI_TB002-500_1x02_P5.00mm_Vertical
J401: Cam LED; JST_XH_B3B-XH-AM_1x03_P2.50mm_Vertical
J402: Aux out; JST_XH_B3B-XH-AM_1x03_P2.50mm_Vertical
J403: Voltage; PinHeader_1x03_P2.54mm_Vertical
J404: Inputs; JST_XH_B4B-XH-AM_1x04_P2.50mm_Vertical
J405, J406: Qwiic; JST_SH_SM04B-SRSS-TB_1x04-1MP_P1.00mm_Horizontal
J407: USB B; USB_B_Receptacle_Horizontal
J801: Feeders; IDC-Header_2x03_P2.54mm_Vertical
J1001, J1101: Pump; TerminalBlock_4UCON_1x02_P3.50mm_Horizontal
J1201, J1301: Valve; TerminalBlock_4UCON_1x02_P3.50mm_Horizontal
J1401, J1501, J1601: Motor; JST_XH_B4B-XH-AM_1x04_P2.50mm_Vertical
Q201: DMP3037LSS-13; SOIC-8_3.9x4.9mm_P1.27mm
Q1001, Q1101: PSMN011-30YLC; LFPAK56
R201, R1202, R1302: 47k; R_0402_HandSolder
R202, R1003, R1103, R1203, R1303: 5k1; R_0402_HandSolder
R203, R204, R305, R306, R307, R308, R309, R310, R405, R1002, R1102: 1k; R_0402_HandSolder
R301, R302, R311, R401, R402, R503, R504, R505, R508, R511, R514, R901, R902, R1401, R1501, R1601: 10k; R_0402_HandSolder
R303, R304: 27R; R_0402_HandSolder
R403, R404, R801: 120R; R_0402_HandSolder
R501, R502, R506, R507, R509, R510, R512, R513, R515, R516: 4k7; R_0402_HandSolder
R1001, R1101: 100k; R_0402_HandSolder
R1201, R1301: 0R; R_0402_HandSolder
R1402, R1403, R1502, R1503, R1602, R1603: 120m; R_1206_HandSolder
RV1401, RV1402, RV1501, RV1502, RV1601, RV1602: MOV; R_0603_HandSolder
SW301: RESET; Tactile_Switch_4.2mm
SW302: BOOTSEL; Tactile_Switch_4.2mm
TP201: GND; TestPoint_Pad_1.0x1.0mm
TP202: 24V; TestPoint_Pad_1.0x1.0mm
TP203: 5V; TestPoint_Pad_D1.0mm
TP204: 3V3; TestPoint_Pad_D1.0mm
TP301: UART; TestPoint_Pad_D1.0mm
U201: VX7805-500; Converter_DCDC_CUI_VX78-500_THT
U202: MIC5317-3.3; SOT-23-5
U301: RP2040; RP2040-QFN-56
U302: W25Q128JVS; SOIC-8_5.23x5.23mm_P1.27mm
U401, U402, U901: 74HC2G34; SOT-363_SC-70-6
U403: TVS; SOT-23-6
U501: PCA9545; TSSOP-20_4.4x6.5mm_P0.65mm
U601, U701: XGZP6857D
U801: MAX3078E; SOIC-8_3.9x4.9mm_P1.27mm
U1201, U1301: DRV120PWR; TSSOP-8_4.4x3mm_P0.65mm
U1401, U1501, U1601: TMC2209; TMC2209-LA
Y301: 12MHz; Crystal_SMD_Abracon_ABM8G-4Pin_3.2x2.5mm

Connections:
+1V1: C310.1, C311.1, C312.1, U301.23 (DVDD), U301.45 (VREG_VOUT), U301.50 (DVDD)
+3V3: C210.1, C301.1, C302.1, C303.1, C304.1, C305.1, C306.1, C307.1, C308.1, C309.1, C315.1, C316.1, C402.1, C501.1, C601.1, C701.1, C801.1, C1402.1, C1502.1, C1602.1, D205.2 (A), J1.1 (VCC), J403.1, J405.2, J406.2, J801.1, J801.2, R301.2, R302.1, R311.2, R501.1, R502.1, R503.1, R504.1, R505.1, R506.1, R507.1, R508.1, R509.1, R510.1, R511.1, R512.1, R513.1, R514.1, R515.1, R516.1, R1401.2, R1501.2, R1601.2, TP204.1, U202.5 (OUT), U301.1 (IOVDD), U301.10 (IOVDD), U301.22 (IOVDD), U301.33 (IOVDD), U301.42 (IOVDD), U301.43 (ADC_AVDD), U301.44 (VREG_IN), U301.48 (USB_VDD), U301.49 (IOVDD), U302.8 (VCC), U402.5 (VCC), U501.20 (VDD), U601.2 (VDD), U701.2 (VDD), U801.8 (VCC), U1401.15 (VCC_IO), U1501.9 (MS1_AD0), U1501.15 (VCC_IO), U1601.9 (MS1_AD0), U1601.10 (MS2_AD1), U1601.15 (VCC_IO)
+5V: C208.1, C209.1, C401.1, C901.1, D204.2 (A), D405.1 (K), J401.2, J402.2, J403.3, TP203.1, U201.3 (Vout), U202.1 (IN), U202.3 (EN), U401.5 (VCC), U901.5 (VCC)
+24V: C202.1, C203.1, C206.1, C207.1, C1202.1, C1302.1, C1403.1, C1411.1, C1412.1, C1413.1, C1414.1, C1503.1, C1511.1, C1512.1, C1513.1, C1514.1, C1603.1, C1611.1, C1612.1, C1613.1, C1614.1, D203.2 (A), D1001.2 (A), D1002.1 (K), D1101.2 (A), D1102.1 (K), D1201.2 (A), D1202.1 (K), D1301.2 (A), D1302.1 (K), FB201.2, J1001.2, J1101.2, J1201.2, J1301.2, TP202.1, U201.1 (Vin), U1201.4 (VIN), U1301.4 (VIN), U1401.22 (VS), U1401.28 (VS), U1501.22 (VS), U1501.28 (VS), U1601.22 (VS), U1601.28 (VS)
/Buffer/IN_A: R901.2, U301.2 (GPIO0), U901.1 (1A)
/Buffer/IN_B: R902.2, U301.3 (GPIO1), U901.3 (2A)
/Buffer/OUT_A: R1001.1, R1002.1, U901.6 (1Y)
/Buffer/OUT_B: R1101.1, R1102.1, U901.4 (2Y)
/Connections/AUX OUT: J402.1, U401.4 (2Y)
/Connections/AUX_OUT: R402.2, U301.17 (GPIO14), U401.3 (2A)
/Connections/CAM LED OUT: J401.1, U401.6 (1Y)
/Connections/CAM_LED: R401.2, U301.18 (GPIO15), U401.1 (1A)
/Connections/IN_1: U301.15 (GPIO12), U402.6 (1Y)
/Connections/IN_2: U301.16 (GPIO13), U402.4 (2Y)
/Connections/MCU_D+: J407.3 (D+), R303.1, U403.1 (D-), U403.6 (D-)
/Connections/MCU_D-: J407.2 (D-), R304.1, U403.3 (D+), U403.4 (D+)
/Connections/QWIIC1_SCK: D403.2 (A2), J405.4, R507.2, U501.6 (SC0)
/Connections/QWIIC1_SDA: D401.2 (A2), J405.3, R506.2, U501.5 (SD0)
/Connections/QWIIC2_SCK: D404.2 (A2), J406.4, R510.2, U501.9 (SC1)
/Connections/QWIIC2_SDA: D402.2 (A2), J406.3, R509.2, U501.8 (SD1)
/I2C Multiplexer/INT: R503.2, U501.17 (~INT)
/I2C Multiplexer/SCL2: R513.2, U501.13 (SC2), U701.4 (SDA)
/I2C Multiplexer/SCL3: R516.2, U501.16 (SC3), U601.4 (SDA)
/I2C Multiplexer/SDA2: R512.2, U501.12 (SD2), U701.5 (SCL)
/I2C Multiplexer/SDA3: R515.2, U501.15 (SD3), U601.5 (SCL)
/I2C Multiplexer/~INT0: R505.2, U501.4 (~INT0)
/I2C Multiplexer/~INT1: R508.2, U501.7 (~INT1)
/I2C Multiplexer/~INT2: R511.2, U501.11 (~INT2)
/I2C Multiplexer/~INT3: R514.2, U501.14 (~INT3)
/I2C Multiplexer/~RESET: R504.2, U501.3 (~RESET)
/Microcontroller/ACT_LED: D301.2 (A), U301.7 (GPIO5)
/Microcontroller/AUX_LED: D302.2 (A), U301.6 (GPIO4)
/Microcontroller/I2C1_SCL: R501.2, U301.9 (GPIO7), U501.18 (SCL)
/Microcontroller/I2C1_SDA: R502.2, U301.8 (GPIO6), U501.19 (SDA)
/Microcontroller/M0_DIAG: U301.40 (GPIO28_ADC2), U1401.11 (DIAG)
/Microcontroller/M0_DIR: U301.38 (GPIO26_ADC0), U1401.19 (DIR)
/Microcontroller/M0_EN: R1401.1, U301.41 (GPIO29_ADC3), U1401.2 (ENN)
/Microcontroller/M0_STEP: U301.39 (GPIO27_ADC1), U1401.16 (STEP)
/Microcontroller/M1_DIAG: U301.36 (GPIO24), U1501.11 (DIAG)
/Microcontroller/M1_DIR: U301.34 (GPIO22), U1501.19 (DIR)
/Microcontroller/M1_EN: R1501.1, U301.37 (GPIO25), U1501.2 (ENN)
/Microcontroller/M1_STEP: U301.35 (GPIO23), U1501.16 (STEP)
/Microcontroller/M2_DIAG: U301.31 (GPIO20), U1601.11 (DIAG)
/Microcontroller/M2_DIR: U301.29 (GPIO18), U1601.19 (DIR)
/Microcontroller/M2_EN: R1601.1, U301.32 (GPIO21), U1601.2 (ENN)
/Microcontroller/M2_STEP: U301.30 (GPIO19), U1601.16 (STEP)
/Microcontroller/QSPI_CS: R311.1, SW302.1, U301.56 (QSPI_SS), U302.1 (~CS)
/Microcontroller/QSPI_SCLK: U301.52 (QSPI_SCLK), U302.6 (CLK)
/Microcontroller/QSPI_SD0: U301.53 (QSPI_SD0), U302.5 (DI(IO0))
/Microcontroller/QSPI_SD1: U301.55 (QSPI_SD1), U302.2 (DO(IO1))
/Microcontroller/QSPI_SD2: U301.54 (QSPI_SD2), U302.3 (IO2)
/Microcontroller/QSPI_SD3: U301.51 (QSPI_SD3), U302.7 (IO3)
/Microcontroller/RS485_OUT_EN: U301.14 (GPIO11), U801.3 (DE)
/Microcontroller/RS485_~IN_EN: U301.13 (GPIO10), U801.2 (~RE)
/Microcontroller/RUN: J1.10 (~RESET), R301.1, SW301.1, U301.26 (RUN)
/Microcontroller/SWCLK: J1.4 (SWCLK), U301.24 (SWCLK)
/Microcontroller/SWD: J1.2 (SWDIO), R302.2, U301.25 (SWD)
/Microcontroller/UART0_TX: R305.2, U301.27 (GPIO16)
/Microcontroller/UART1_RX: U301.12 (GPIO9), U801.1 (RO)
/Microcontroller/UART1_TX: U301.11 (GPIO8), U801.4 (DI)
/Microcontroller/VALVE_A: U301.4 (GPIO2), U1201.8 (EN)
/Microcontroller/VALVE_B: U301.5 (GPIO3), U1301.8 (EN)
/Microcontroller/XIN: C313.1, U301.20 (XIN), Y301.1
/Microcontroller/XOUT: R310.1, U301.21 (XOUT)
/Power/DCIN: F201.1, J201.1, J202.1
/Power/gate: D202.2 (A), Q201.4 (G), R201.1
/Power/post fuse: D201.1 (K), F201.2, Q201.5 (D), Q201.6 (D), Q201.7 (D), Q201.8 (D)
/Power/post polarity: C201.1, D202.1 (K), FB201.1, Q201.1 (S), Q201.2 (S), Q201.3 (S)
/Pump A/switched: D1002.2 (A), J1001.1, Q1001.5 (D), R1003.2
/Pump B/switched: D1102.2 (A), J1101.1, Q1101.5 (D), R1103.2
/RS485/RS-485+: J801.5, R801.1, U801.6 (A)
/RS485/RS-485-: J801.6, R801.2, U801.7 (B)
/TMC_UART: R305.1, TP301.1, U301.28 (GPIO17), U1401.14 (PDN_UART), U1501.14 (PDN_UART), U1601.14 (PDN_UART)
/Valve A/KEEP: C1201.1, U1201.1 (KEEP)
/Valve A/OSC: R1201.2, U1201.3 (OSC)
/Valve A/PEAK: R1202.2, U1201.2 (PEAK)
/Valve A/switched: D1202.2 (A), J1201.1, R1203.2, U1201.7 (OUT)
/Valve B/KEEP: C1301.1, U1301.1 (KEEP)
/Valve B/OSC: R1301.2, U1301.3 (OSC)
/Valve B/PEAK: R1302.2, U1301.2 (PEAK)
/Valve B/switched: D1302.2 (A), J1301.1, R1303.2, U1301.7 (OUT)
/X Motor/5VOUT: C1404.1, U1401.8 (5VOUT)
/X Motor/BRA: C1406.1, R1403.2, U1401.23 (BRA)
/X Motor/BRB: C1405.1, R1402.2, U1401.27 (BRB)
/X Motor/CPI: C1401.2, U1401.5 (CPI)
/X Motor/CPO: C1401.1, U1401.4 (CPO)
/X Motor/OA1: FB1403.1, U1401.24 (OA1)
/X Motor/OA2: FB1404.1, U1401.21 (OA2)
/X Motor/OB1: FB1402.1, U1401.26 (OB1)
/X Motor/OB2: FB1401.1, U1401.1 (OB2)
/X Motor/VCP: C1403.2, U1401.6 (VCP)
/Y1 Motor/5VOUT: C1504.1, U1501.8 (5VOUT)
/Y1 Motor/BRA: C1506.1, R1503.2, U1501.23 (BRA)
/Y1 Motor/BRB: C1505.1, R1502.2, U1501.27 (BRB)
/Y1 Motor/CPI: C1501.2, U1501.5 (CPI)
/Y1 Motor/CPO: C1501.1, U1501.4 (CPO)
/Y1 Motor/OA1: FB1503.1, U1501.24 (OA1)
/Y1 Motor/OA2: FB1504.1, U1501.21 (OA2)
/Y1 Motor/OB1: FB1502.1, U1501.26 (OB1)
/Y1 Motor/OB2: FB1501.1, U1501.1 (OB2)
/Y1 Motor/VCP: C1503.2, U1501.6 (VCP)
/Y2 Motor/5VOUT: C1604.1, U1601.8 (5VOUT)
/Y2 Motor/BRA: C1606.1, R1603.2, U1601.23 (BRA)
/Y2 Motor/BRB: C1605.1, R1602.2, U1601.27 (BRB)
/Y2 Motor/CPI: C1601.2, U1601.5 (CPI)
/Y2 Motor/CPO: C1601.1, U1601.4 (CPO)
/Y2 Motor/OA1: FB1603.1, U1601.24 (OA1)
/Y2 Motor/OA2: FB1604.1, U1601.21 (OA2)
/Y2 Motor/OB1: FB1602.1, U1601.26 (OB1)
/Y2 Motor/OB2: FB1601.1, U1601.1 (OB2)
/Y2 Motor/VCP: C1603.2, U1601.6 (VCP)
GND: C201.2, C202.2, C203.2, C206.2, C207.2, C208.2, C209.2, C210.2, C301.2, C302.2, C303.2, C304.2, C305.2, C306.2, C307.2, C308.2, C309.2, C310.2, C311.2, C312.2, C313.2, C314.2, C315.2, C316.2, C401.2, C402.2, C501.2, C601.2, C701.2, C801.2, C901.2, C1201.2, C1202.2, C1301.2, C1302.2, C1402.2, C1404.2, C1405.2, C1406.2, C1407.2, C1408.2, C1409.2, C1410.2, C1411.2, C1412.2, C1413.2, C1414.2, C1502.2, C1504.2, C1505.2, C1506.2, C1507.2, C1508.2, C1509.2, C1510.2, C1511.2, C1512.2, C1513.2, C1514.2, C1602.2, C1604.2, C1605.2, C1606.2, C1607.2, C1608.2, C1609.2, C1610.2, C1611.2, C1612.2, C1613.2, C1614.2, D201.2 (A), D401.1 (A1), D402.1 (A1), D403.1 (A1), D404.1 (A1), H101.1, H102.1, H103.1, H104.1, J1.3 (GND), J1.5 (GND), J1.9 (GNDDetect), J201.2, J202.2, J401.3, J402.3, J404.4, J405.1, J405.MP (MountPin), J406.1, J406.MP (MountPin), J407.4 (GND), J407.5 (Shield), J801.3, J801.4, Q1001.1 (S), Q1001.2 (S), Q1001.3 (S), Q1101.1 (S), Q1101.2 (S), Q1101.3 (S), R201.2, R202.2, R203.2, R204.2, R306.1, R307.1, R308.2, R309.2, R401.1, R402.1, R405.2, R901.1, R902.1, R1001.2, R1101.2, R1201.1, R1202.1, R1301.1, R1302.1, R1402.1, R1403.1, R1502.1, R1503.1, R1602.1, R1603.1, TP201.1, U201.2 (GND), U202.2 (GND), U301.19 (TESTEN), U301.57 (GND), U302.4 (GND), U401.2 (GND), U402.2 (GND), U403.2 (GND), U501.1 (A0), U501.2 (A1), U501.10 (VSS), U601.6 (GND), U701.6 (GND), U801.5 (GND), U901.2 (GND), U1201.5 (GND), U1301.5 (GND), U1401.3 (GND), U1401.9 (MS1_AD0), U1401.10 (MS2_AD1), U1401.13 (CLK), U1401.18 (GND), U1401.25 (GND), U1401.29 (PAD), U1501.3 (GND), U1501.10 (MS2_AD1), U1501.13 (CLK), U1501.18 (GND), U1501.25 (GND), U1501.29 (PAD), U1601.3 (GND), U1601.13 (CLK), U1601.18 (GND), U1601.25 (GND), U1601.29 (PAD), Y301.2, Y301.4
unnamed: C314.1, R310.2, Y301.3
unnamed: C1407.1, FB1402.2, J1401.3, RV1401.2
unnamed: C1408.1, FB1404.2, J1401.1, RV1402.2
unnamed: C1409.1, FB1401.2, J1401.4, RV1401.1
unnamed: C1410.1, FB1403.2, J1401.2, RV1402.1
unnamed: C1507.1, FB1502.2, J1501.3, RV1501.2
unnamed: C1508.1, FB1504.2, J1501.1, RV1502.2
unnamed: C1509.1, FB1501.2, J1501.4, RV1501.1
unnamed: C1510.1, FB1503.2, J1501.2, RV1502.1
unnamed: C1607.1, FB1602.2, J1601.3, RV1601.2
unnamed: C1608.1, FB1604.2, J1601.1, RV1602.2
unnamed: C1609.1, FB1601.2, J1601.4, RV1601.1
unnamed: C1610.1, FB1603.2, J1601.2, RV1602.1
unnamed: D203.1 (K), R202.1
unnamed: D204.1 (K), R203.1
unnamed: D205.1 (K), R204.1
unnamed: D301.1 (K), R308.1
unnamed: D302.1 (K), R309.1
unnamed: D405.2 (A), D406.2 (A), J407.1 (VBUS), U403.5 (VBUS)
unnamed: D406.1 (K), R405.1
unnamed: D1001.1 (K), R1003.1
unnamed: D1101.1 (K), R1103.1
unnamed: D1201.1 (K), R1203.1
unnamed: D1301.1 (K), R1303.1
unnamed: J403.2, J404.1
unnamed: J404.2, R403.2
unnamed: J404.3, R404.2
unnamed: Q1001.4 (G), R1002.2
unnamed: Q1101.4 (G), R1102.2
unnamed: R303.2, U301.47 (USB_DP)
unnamed: R304.2, U301.46 (USB_DM)
unnamed: R306.2, SW301.2
unnamed: R307.2, SW302.2
unnamed: R403.1, U402.1 (1A)
unnamed: R404.1, U402.3 (2A)

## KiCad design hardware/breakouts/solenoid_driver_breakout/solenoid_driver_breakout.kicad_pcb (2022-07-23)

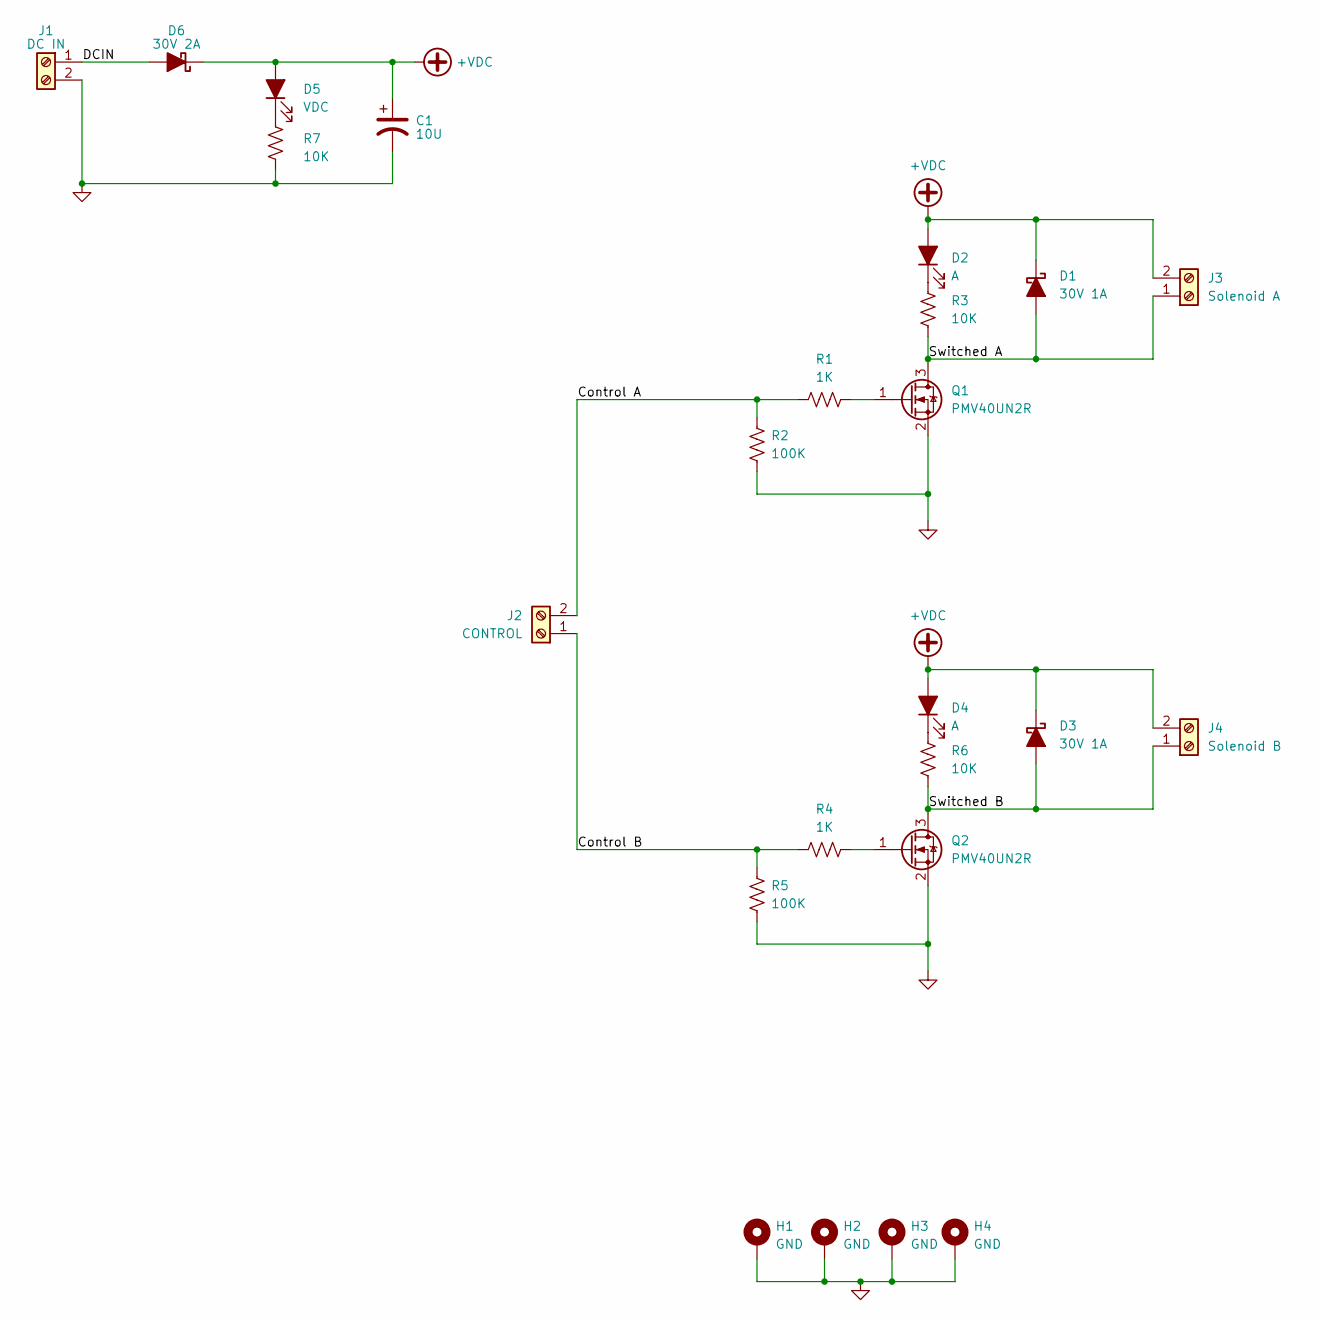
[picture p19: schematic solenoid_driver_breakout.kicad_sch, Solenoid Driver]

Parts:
C1: 10U; C_0805_2012Metric_Pad1.18x1.45mm_HandSolder
D1, D3: 30V 1A; D_SOD-128
D2, D4: A; LED_0805_Kingbright_APT2012; mpn APT2012EC
D5: VDC; LED_0805_Kingbright_APT2012; mpn APT2012EC
D6: 30V 2A; D_SOD-128
H1, H2, H3, H4: GND; MountingHole_3mm_Pad
J1: DC IN; TerminalBlock_4UCON_1x02_P3.50mm_Horizontal
J2: CONTROL; TerminalBlock_4UCON_1x02_P3.50mm_Horizontal
J3: Solenoid A; TerminalBlock_4UCON_1x02_P3.50mm_Horizontal
J4: Solenoid B; TerminalBlock_4UCON_1x02_P3.50mm_Horizontal
Q1, Q2: PMV40UN2R; SOT-23
R1, R4: 1K; R_0603_1608Metric_Pad0.98x0.95mm_HandSolder
R2, R5: 100K; R_0603_1608Metric_Pad0.98x0.95mm_HandSolder
R3, R6, R7: 10K; R_0603_1608Metric_Pad0.98x0.95mm_HandSolder; mpn AC0603FR-075K1L

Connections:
+VDC: C1.1, D1.1 (K), D2.2 (A), D3.1 (K), D4.2 (A), D5.2 (A), D6.1 (K), J3.2, J4.2
/Control A: J2.2, R1.1, R2.1
/Control B: J2.1, R4.1, R5.1
/DCIN: D6.2 (A), J1.1
/Switched A: D1.2 (A), J3.1, Q1.3 (D), R3.2
/Switched B: D3.2 (A), J4.1, Q2.3 (D), R6.2
GND: C1.2, H1.1, H2.1, H3.1, H4.1, J1.2, Q1.2 (S), Q2.2 (S), R2.2, R5.2, R7.2
unnamed: D2.1 (K), R3.1
unnamed: D5.1 (K), R7.1
unnamed: Q1.1 (G), R1.2
unnamed: Q2.1 (G), R4.2
unnamed: D4.1 (K), R6.1

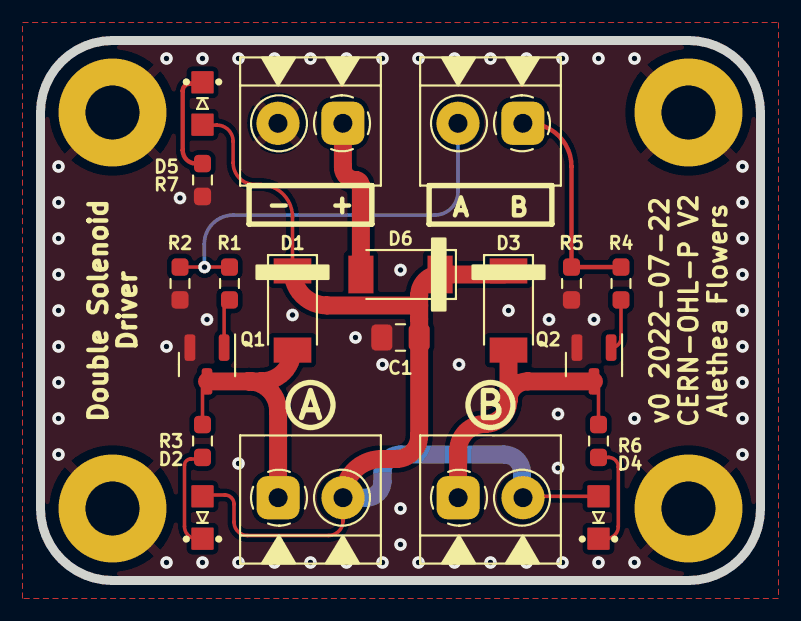
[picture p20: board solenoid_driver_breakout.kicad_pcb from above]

Board: 2 copper layers, 40.0 x 30.0 mm, 24 parts (0 on the bottom side), 12 nets.

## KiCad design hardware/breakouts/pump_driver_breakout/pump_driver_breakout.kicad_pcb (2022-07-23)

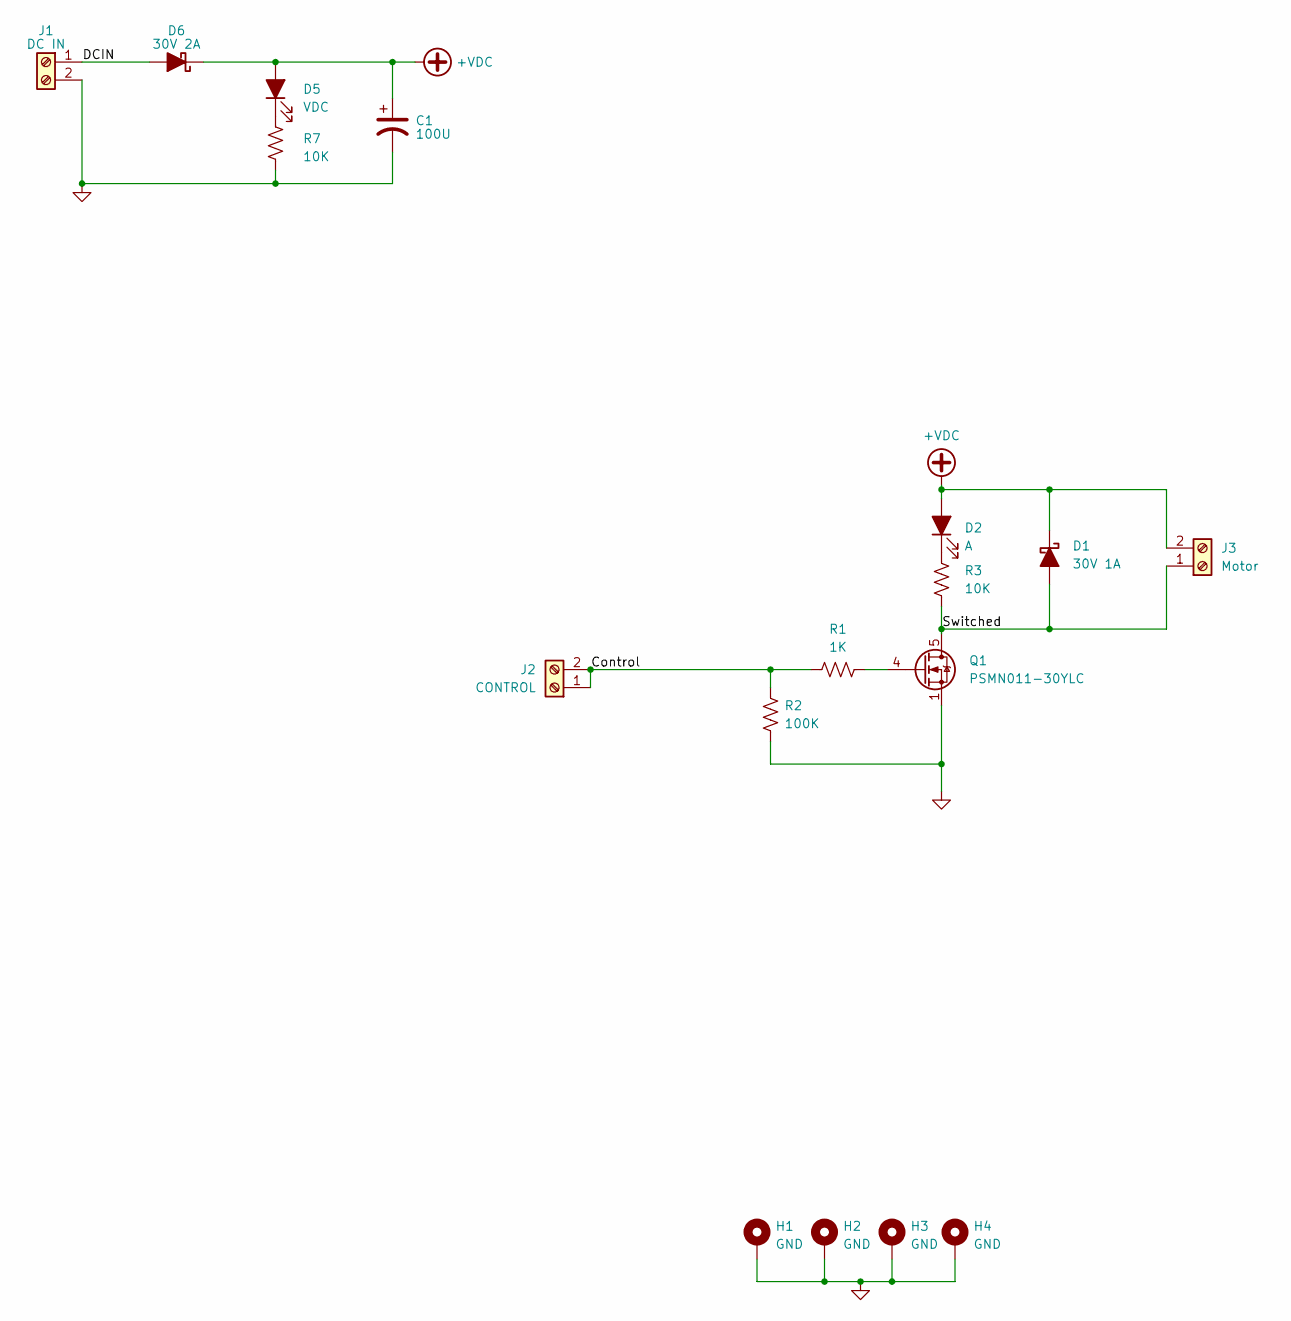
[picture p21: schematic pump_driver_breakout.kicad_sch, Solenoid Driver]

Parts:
C1: 100U; C_1210_3225Metric_Pad1.33x2.70mm_HandSolder
D1: 30V 1A; D_SOD-128
D2: A; LED_0805_Kingbright_APT2012; mpn APT2012EC
D5: VDC; LED_0805_Kingbright_APT2012; mpn APT2012EC
D6: 30V 2A; D_SOD-128
H1, H2, H3, H4: GND; MountingHole_3mm_Pad
J1: DC IN; TerminalBlock_4UCON_1x02_P3.50mm_Horizontal
J2: CONTROL; TerminalBlock_4UCON_1x02_P3.50mm_Horizontal
J3: Motor; TerminalBlock_4UCON_1x02_P3.50mm_Horizontal
Q1: PSMN011-30YLC; LFPAK56
R1: 1K; R_0603_1608Metric_Pad0.98x0.95mm_HandSolder
R2: 100K; R_0603_1608Metric_Pad0.98x0.95mm_HandSolder
R3, R7: 10K; R_0603_1608Metric_Pad0.98x0.95mm_HandSolder; mpn AC0603FR-075K1L

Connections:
+VDC: C1.1, D1.1 (K), D2.2 (A), D5.2 (A), D6.1 (K), J3.2
/Control: J2.1, J2.2, R1.1, R2.1
/DCIN: D6.2 (A), J1.1
/Switched: D1.2 (A), J3.1, Q1.5 (D), R3.2
GND: C1.2, H1.1, H2.1, H3.1, H4.1, J1.2, Q1.1 (S), Q1.2 (S), Q1.3 (S), R2.2, R7.2
unnamed: D2.1 (K), R3.1
unnamed: D5.1 (K), R7.1
unnamed: Q1.4 (G), R1.2

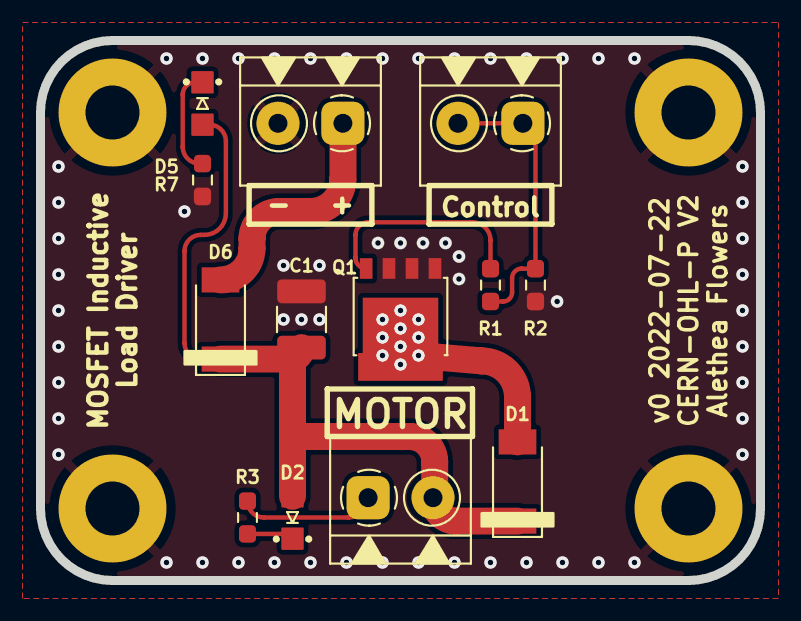
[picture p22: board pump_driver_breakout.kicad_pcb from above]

Board: 2 copper layers, 40.0 x 30.0 mm, 17 parts (0 on the bottom side), 8 nets.

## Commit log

2022-07-09 Initial version
    [connections.kicad_sch, head_board.kicad_pcb, head_board.kicad_sch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]
2022-07-10 Switch to power module
    [head_board.kicad_pcb, head_board.kicad_sch, power.kicad_sch]
2022-07-22 Initial sketch for solenoid driver breakout
    [solenoid_driver_breakout.kicad_pcb, solenoid_driver_breakout.kicad_sch]
2022-07-22 Switch solenoid driver to dual low-side switches
    [solenoid_driver_breakout.kicad_pcb, solenoid_driver_breakout.kicad_sch]
2022-07-22 Add mechanical parts
    [x-gantry-back.FCStd, x-gantry-front.FCStd]
2022-07-23 Add pump driver breakout
    [pump_driver_breakout.kicad_pcb, pump_driver_breakout.kicad_sch]
2022-07-23 Add smart solenoid drivers
    [drv103_solenoid_driver_breakout.kicad_pcb, drv103_solenoid_driver_breakout.kicad_sch, pump_driver_breakout.kicad_pcb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]
2022-07-27 v1 revision to the schematic
    [connections.kicad_sch, head_board.kicad_sch, mcu.kicad_sch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]
2022-07-27 Footprints assigned
    [connections.kicad_sch, head_board.kicad_sch, mcu.kicad_sch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]
2022-07-28 Finish up layout for v1, ended up removing some stuff
    [connections.kicad_sch, head_board.kicad_pcb, head_board.kicad_sch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]
2022-07-28 Add buddy board schematic to references
2022-08-28 Add actual component values
    [drv103_solenoid_driver_breakout.kicad_sch]
2022-08-28 Add dimensions
    [head_board.kicad_pcb, tail_board.kicad_pcb]
2022-08-28 Update x-gantry-back to match head board
    [x-gantry-back.FCStd]
2022-09-08 V2 of the head board (Jellyfish)
    [connections.kicad_sch, head_board.kicad_pcb, head_board.kicad_sch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]
2022-09-08 V1 of the tailboard
    [head_board.kicad_sch, tail_board.kicad_pcb, tail_board.kicad_sch]
2022-09-08 Replace veritcal connectors with horizontal ones
    [connections.kicad_sch, head_board.kicad_pcb, head_board.kicad_sch]
2022-09-09 Move breakouts into a subdirectory
    [drv103_solenoid_driver_breakout.kicad_pcb, drv103_solenoid_driver_breakout.kicad_sch, pump_driver_breakout.kicad_pcb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]
2022-09-09 Remove unused footprints
2022-09-09 Clone jellyfish to starfish
    [connections.kicad_sch, mcu.kicad_sch, motor.kicad_sch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]
2022-09-10 First pass at schematic for starfish
    [buffer.kicad_sch, connections.kicad_sch, i2c_mux.kicad_sch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]
2022-09-10 Mostly finished starfish schematic, ready for layout!
    [buffer.kicad_sch, connections.kicad_sch, i2c_mux.kicad_sch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]
2022-09-11 Update spacing between top and bottom mounting holes
    [x-gantry-back.FCStd, x-gantry-front.FCStd]
2022-09-12 First pass at layout and routing
    [buffer.kicad_sch, connections.kicad_sch, i2c_mux.kicad_sch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]
2022-09-12 Cleanup a bit
    [starfish.kicad_pcb]
2022-09-13 Layout and routing mostly done! Just gotta make it prettier!
    [connections.kicad_sch, motor.kicad_sch, power.kicad_sch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]
2022-09-13 I think it might be (99%) done!
    [starfish.kicad_pcb]
2022-09-13 Redo ground stitching
    [starfish.kicad_pcb]
2022-09-13 Add ground pour to incu2
2022-09-13 Run through purchasing, update some cap sizes
    [buffer.kicad_sch, connections.kicad_sch, i2c_mux.kicad_sch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]
2022-09-14 Update Jellyfish with some stuff from Starfish
    [connections.kicad_sch, jellyfish.kicad_pcb, jellyfish.kicad_sch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]
2022-09-14 touchup tailboard
    [jellyfish.kicad_pcb, jellyfish_tailboard.kicad_pcb, jellyfish_tailboard.kicad_sch]
2022-09-14 Send off for manufacturing
    [buffer.kicad_sch, connections.kicad_sch, i2c_mux.kicad_sch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]
2022-09-29 Update gantries based on Lumen V3
    [x-gantry-back.FCStd, x-gantry-front.FCStd]
2022-09-29 Add x-gantry-block-mount
    [x-gantry-block-mount.FCStd]
2022-09-29 Add z-gantry with mounting holes for extra stuff
    [z-gantry.FCStd]
2022-09-29 Add drag chain mounts
    [drag chain mount.FCStd, front-drag-chain-mount.FCStd]
2022-09-29 Add STEP version of Jellyfish's PCB
    [jellyfish-pcb.FCStd]
2022-09-29 Add assembly
2022-10-14 Update license on all hardware files
    [buffer.kicad_sch, connections.kicad_sch, i2c_mux.kicad_sch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]
2022-10-14 Fix I2C connections
    [starfish.kicad_sch]
2022-11-04 starfish: fix input diode value
    [connections.kicad_sch]
2022-11-04 starfish: change pin shape
    [mcu.kicad_sch]
2022-11-04 starfish: fix diode values
    [power.kicad_sch]
2022-11-04 starfish: update mosfet value and rating
    [pumps.kicad_sch]
2022-11-04 starfish: minor change to text size
    [rs485.kicad_sch]
2022-11-04 starfish: update BOM values
    [starfish.kicad_sch]
2022-11-28 Add block mount w/ proximity sensor
    [x-gantry-block-mount-heat-set.FCStd, x-gantry-block-mount-with-prox.FCStd]
2022-12-06 Starfish v1
    - Switch from DRV120 smart solenoid drivers to MOSFETs so that a wider variety of solenoids can be controlled. RP2040 PWM should be used along with these MOSFETs to prevent solenoids from overheating.
    - Move all power lines out of inner copper layers and onto back copper.
    - Small changes to signal routing to accommodate new power routing.
    [buffer.kicad_sch, connections.kicad_sch, i2c_mux.kicad_sch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]
2022-12-19 starfish: remove feeder header and use screw terminals for rs-485
    [buffer.kicad_sch, connections.kicad_sch, i2c_mux.kicad_sch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]
2022-12-19 remove drv103 and drv120 breakouts
    [drv103_solenoid_driver_breakout.kicad_pcb, drv103_solenoid_driver_breakout.kicad_sch, smart_solenoid_driver_breakout.kicad_pcb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]
2022-12-19 Add RS-485 to feeder board
    [rs485-feeder-adapter.kicad_pcb, rs485-feeder-adapter.kicad_sch]

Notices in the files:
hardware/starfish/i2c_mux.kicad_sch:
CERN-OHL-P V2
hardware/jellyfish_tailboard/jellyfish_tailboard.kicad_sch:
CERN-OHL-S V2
